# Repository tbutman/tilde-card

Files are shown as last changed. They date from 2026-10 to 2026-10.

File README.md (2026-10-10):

# Tilde card

A business card you print yourself, made to go with [Tilde](https://taptilde.com), the
Android app that turns your phone into an NFC business card. The front has a QR code that opens your
website. Add an NFC sticker, sealed inside during the print, and people can tap it with their phone
too.

**Free and open source.** The model is free to download, print and change: MIT for the source,
CC BY 4.0 on MakerWorld. No account, sign-up, subscription or payment, and no service in between:
the card links straight to your own website. It works without the app too: phones read it on their
own, and any NFC app can write the sticker. More about Tilde and the card:
[taptilde.com](https://taptilde.com).

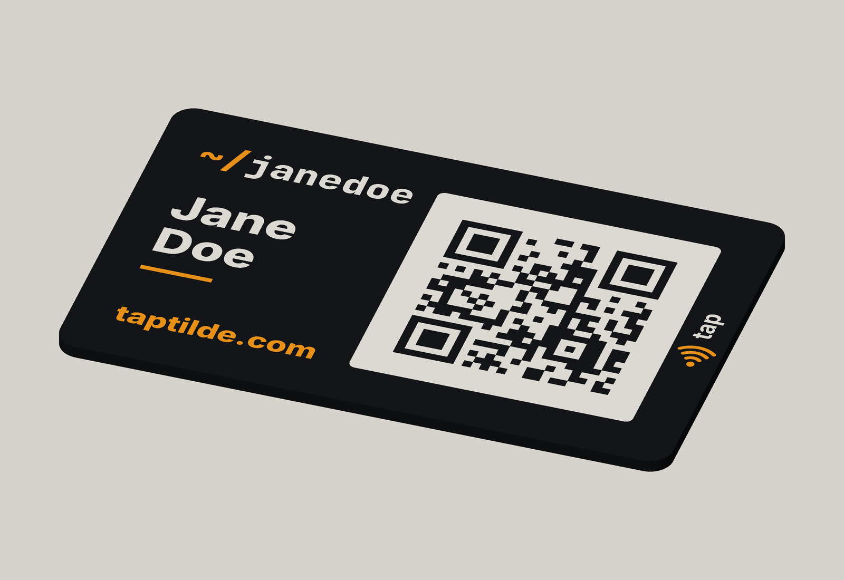
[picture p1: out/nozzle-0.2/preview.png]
The card


| Front | Back |
| --- | --- |
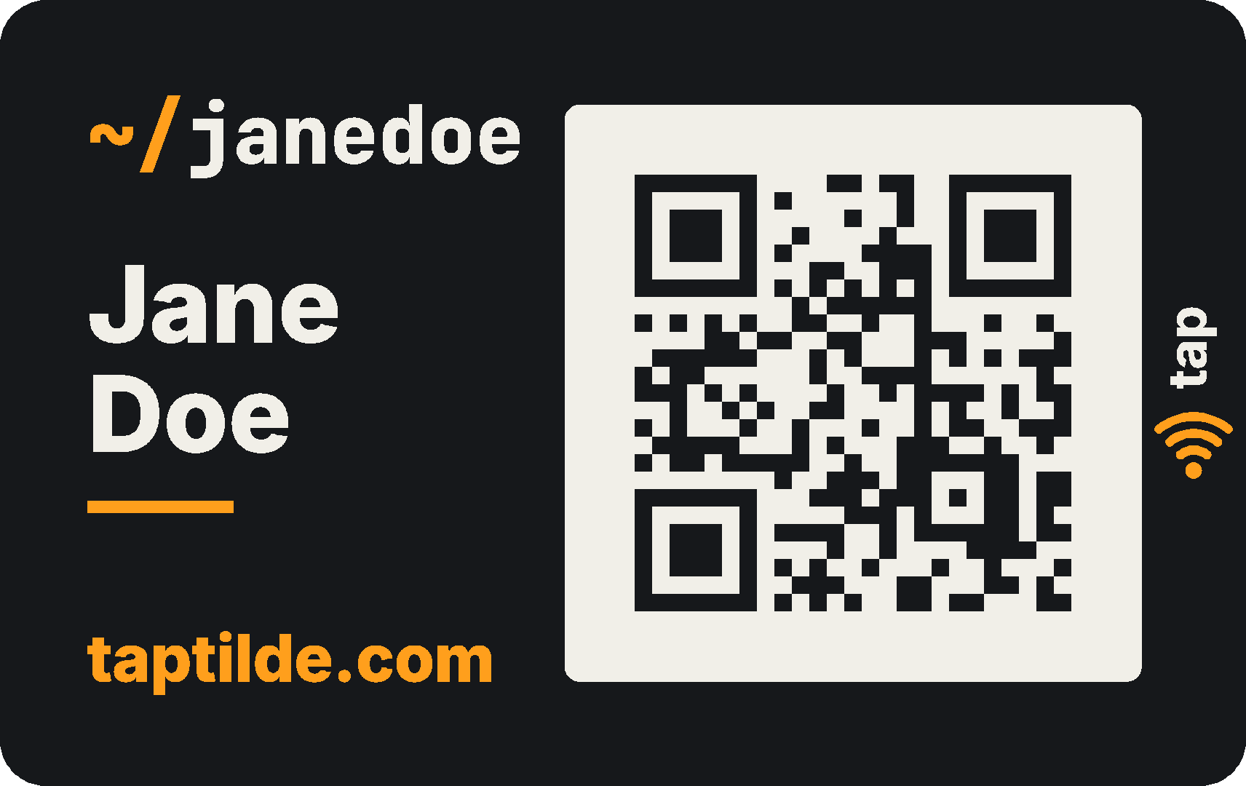
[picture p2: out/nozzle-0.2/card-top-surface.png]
Front
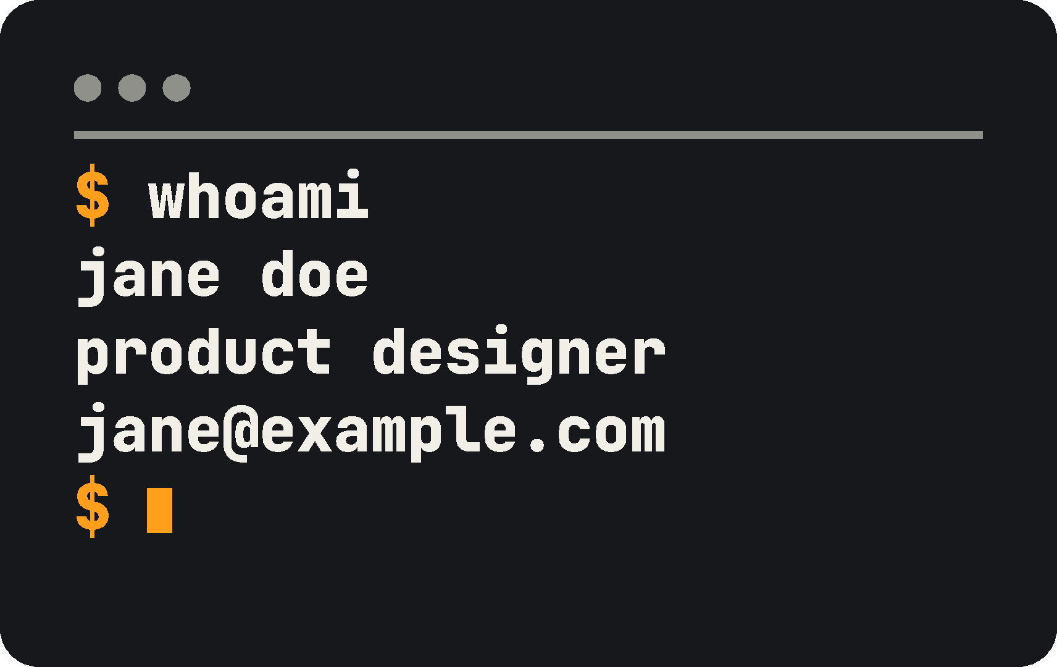
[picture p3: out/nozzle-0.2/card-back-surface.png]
Back
|  |  |

- **Credit-card size** (85.6 × 54 mm), 1.6 mm thick (1.8 mm with an NFC sticker, 2.0 mm with a thick one), so it fits
  a wallet.
- **A QR code that works with any phone camera.** It's the heart of the card.
- **NFC is optional.** If you add it, the printer pauses halfway, you drop in a sticker, and the
  rest of the card prints over it, sealing it inside; iPhones and Android phones with NFC then open
  your link when tapped against the marked spot. Without one, it's a QR card: no stickers and no
  pause.
- **Three backs to choose from:** a terminal window (`$ whoami`, as above), a plain one, or none,
  which prints fastest. Both designs print three lines you choose, such as your name, title and
  email.
- **Four colors of PLA**, printed all at once on a printer with an AMS (or another multi-color
  system). No painting or gluing.

The files in `out/` are a sample card for Jane Doe, an example person, linking to taptilde.com. To
make yours, type in your name, links and colors on MakerWorld (coming soon) or in OpenSCAD's
Customizer: see [Make it yours](PRINTING.md#make-it-yours). The Customizer starts on the 0.4 mm
nozzle, the faster print and the one most printers come with; see
[Choose a nozzle](PRINTING.md#choose-a-nozzle).

## Print one

[PRINTING.md](PRINTING.md) walks through it step by step: which nozzle to use, the slicer settings
and, if you add NFC, which stickers to buy, the pause for the sticker and how to put your link on
it.

## Tilde, the app it goes with

[Tilde](https://github.com/tbutman/tilde) is a free, open-source Android app (MIT, no account, no ads,
no internet permission) that does what the card does, from your phone: people tap your phone, or scan the code on its screen, to get your website,
contact card, WhatsApp or LinkedIn. It also writes your link onto the card's NFC sticker
(**Settings → Write a sticker**). Get it at [taptilde.com](https://taptilde.com).

## For developers

The model is written in [OpenSCAD](https://openscad.org): `card.scad` holds every size and every
line of text as a setting. [docs/DESIGN.md](docs/DESIGN.md) covers how it's built and checked,
the design decisions, and the print log.

## License

The model and scripts are [MIT](LICENSE) © Thomas Butman. The printable files on MakerWorld are
shared under [CC BY 4.0](https://creativecommons.org/licenses/by/4.0/): print, remix and sell
cards freely, with credit. The fonts in `fonts/` are Inter and JetBrains Mono, under the SIL Open
Font License (see the license files beside them).

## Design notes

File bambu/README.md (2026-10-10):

# Bambu Studio process presets

Two process presets for the **Bambu Lab A1 mini**, one per nozzle. They build on the A1 mini's
standard processes and change only what the card needs:

| Preset | Builds on | Changes |
| --- | --- | --- |
| `Tilde card 0.4 mm` | 0.20mm Standard @BBL A1M | Sparse infill 100% with the Rectilinear pattern (`zig-zag` in the file), Arachne walls, Monotonic line bottom surface, and paint penetration layers top 2 / bottom 2 |
| `Tilde card 0.2 mm` | 0.10mm Standard @BBL A1M 0.2 nozzle | The same, with paint penetration layers top 4 / bottom 4 |

The paint penetration layers matter for a 3MF from MakerWorld's Customize: its colors are painted
onto one shape, and Bambu Studio paints each face this many layers deep. These values keep the
back's colors to its 0.4 mm inlays, above the black lid over the sticker. Bambu also paints the
pocket's ceiling black upward as a bottom face, so the bottom value is 2 (4): more would fill the
letters over the pocket with black. The front's white is then 0.4 mm with black behind it, which
hides the sticker. With the defaults (top 5 on 0.4 mm, 7 on 0.2 mm) the back's letters go through
the lid and print onto the sticker. The STL parts in `out/` aren't painted, so they're not affected.

Both presets are tested on real prints of a sticker card from a Customize 3MF, paint penetration
layers included (October 8, 2026): the 0.4 mm one fully, the 0.2 mm one through to the last layer,
where the 0.2 mm nozzle clogged, so its back's white came out one layer short. A tap test and
photos of the 0.2 mm card are still to come. Before printing
a sticker card, check the lid in Preview (see [PRINTING.md](../PRINTING.md#set-up-the-print-in-bambu-studio), step 7).

**To use them:** in Bambu Studio, **File → Import → Import Configs**, choose
`tilde_card_bambu_printer_settings.zip` (or one of the `.json` files), then pick **Tilde card 0.4 mm** or
**Tilde card 0.2 mm** under **Process**, with the A1 mini and the matching nozzle selected. The
pause for an NFC sticker is still added by hand (see [PRINTING.md](../PRINTING.md#add-the-pause-for-the-nfc-sticker)).

**Updating from an earlier version?** Delete the old Tilde card preset first, or check that Top
paint penetration layers shows 2 (0.4 mm) or 4 (0.2 mm) after importing. Bambu Studio may keep an
existing preset with the same name, and an older export doesn't set the paint layers.

**After opening the 3MF, choose the process again** (Tilde card 0.4 mm or 0.2 mm, or your adjusted
standard process): the 3MF from Customize is a Bambu project file and brings Bambu's standard
process with it. If the name shows an asterisk, re-select it and discard the changes. Then check
Top paint penetration layers shows 2 (0.4 mm) or 4 (0.2 mm).

On another printer, start from its own standard process and make the four changes by hand
(see [PRINTING.md](../PRINTING.md#set-up-the-print-in-bambu-studio)).

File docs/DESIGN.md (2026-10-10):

# Design and build notes

The technical side of the card: how the model is built, checked and generated. To print one, see
[PRINTING.md](../PRINTING.md).

## Specifications

- **Size:** ID-1 (85.60 × 53.98 mm, 3.2 mm corners), 1.6 mm thick as a QR card; 1.8 mm with thin
  stickers, 2.0 mm with thick ones.
- **QR code:** generated in `card.scad` from `qr_code_link`: byte mode, version 1–3 with error
  correction M (or L when M can't hold the link), up to 53 characters. The modules scale to fill a
  fixed 39.6 mm white field that includes the full 4-module quiet zone: 1.37 mm (version 1),
  1.2 mm (version 2, as for `https://tbutman.com/hello`) or 1.07 mm (version 3). Black modules on
  white; the white is a 0.6 mm inlay, flush with the face.
- **NFC (optional):** `nfc_sticker = "none"` leaves out the pocket and the tap marker, for a QR
  card with no pause; the QR code keeps its place. Otherwise, an NTAG215 sticker (22–25 mm across, 25.5 mm at most) in a 25.8 mm pocket against the right edge, under the QR code,
  with 0.8 mm of plastic between it and the front face (the 0.6 mm inlay and 0.2 mm of black, so
  the tag can't show through the white field). The pocket is 0.2 mm deep for stickers 0.10–0.20 mm
  thick, or 0.4 mm deep with `nfc_sticker = "thick"`. Over the tag (the first layers after the
  pause) is a solid black lid of 0.4 mm (`nfc_lid_t`), then the back's inlays, which are 0.4 mm deep
  on a sticker card (0.6 mm on a QR card): the first print with a sticker had the back's letters
  printed straight onto the sticker, and they dragged into strings. So a sticker card is 1.8 mm
  thick, or 2.0 mm with thick stickers. A tap marker (NFC waves, not the EMVCo payment symbol, and
  `tap_label`, "tap" by default), turned to read upwards, sits in the strip right of the QR code,
  over the tag. The waves and the label each take one of the card's colors (`tap_waves_color`,
  `tap_label_color`: `accent`, `light` or `chrome`; by default the accent color for the waves and the light color for the label), on
  both sides; each goes into that color's inlay part, flush with the face. A longer label shrinks to fit the QR code's height, down to the
  nozzle's smallest text (about 14 characters on 0.4 mm, 17 on 0.2 mm); an empty one leaves just
  the waves. `back_tap_mark` (`waves` or `label`) repeats the marker on the back: the waves, plus
  `tap_label` for `label`, turned like the front's, in the same strip seen from behind, so it sits
  over the tag. With the mark on, the back's lines (and the terminal window) start 2.69 mm further
  right, a `text_gap` past the strip, on all three styles; with it off, nothing moves.
  The back's mark uses the same two colors. On a None back the mark brings back the back's inlay
  layers (about one more color change per layer: 6 layers on 0.2 mm, 3 on 0.4 mm), and with the
  window bar color the gray filament too; the window bar color on the front adds it to the front's
  layers the same way.
  `verify.py` lists the sample's reviewed spots at both positions.
- **Back:** `back_style` is `terminal`, `plain` or `none` (plain black). Both designs print the
  same three lines, `back_line_1` to `back_line_3`; an empty one is skipped. The terminal style is
  a window: a gray title bar (three dots and a rule), then a session (`$ ` and `terminal_command`,
  `whoami` by default, the three lines, a cursor) anchored under it, inlaid 0.6 mm (0.4 mm with a sticker). The plain style
  prints the lines in Inter, centered vertically: the first larger, the second in the accent color. Both shrink
  to fit like the front. The back reads correctly when the card is turned over sideways.
- **Print orientation:** the front prints face-down (`face_down = "front"`), because the plate
  side came out flat and matte on the first sample and the top side came out ridged. The STLs
  are exported already lying that way: the model turned over about its long axis, a rotation
  rather than a mirror. `verify.py` turns each face back the right way round before checking it.
- **Type:** Inter (ExtraBold; Bold for "tap" on the 0.2 mm version) and JetBrains Mono ExtraBold, the site's
  own typefaces, unaltered. Tuned for a 0.2 mm nozzle on 0.1 mm layers: cap heights of 2.6 mm or
  more, every stroke at least 0.3 mm and every gap at least 0.22 mm, on both faces.

Two versions are built from the same model, `out/nozzle-0.2/` and `out/nozzle-0.4/`; see
[Choose a nozzle](../PRINTING.md#choose-a-nozzle).

## Files

| Path | What |
| --- | --- |
| `card.scad` | The parametric model, one self-contained file. The Customizer sections at the top are the settings people change, one help line each (MakerWorld shows only one); `[Hidden]` holds the layout. The defaults are the sample card, Jane Doe. |
| `card.local.example.scad` | A template for `card.local.scad` (git-ignored): your own settings, one `setting = value;` per line, which `build.sh` passes to OpenSCAD as `-D` flags. |
| `makerworld/tilde-card.scad` | The copy uploaded to MakerWorld's customizer, written by `scripts/make_makerworld.py`: no font file lines, and the example person Jane Doe as the defaults. Never edited by hand. |
| `out/makerworld-sample/`, `out/makerworld-sample-qr-only-plain/` | Cards built from the MakerWorld copy, to check it renders and passes the checks: the default (on its default 0.4 mm nozzle, checked against that nozzle's limits), and one with no NFC sticker and the plain back (its first line typed as "Jane Doe"). |
| `out/nozzle-{0.2,0.4}/card-{body,light,accent,chrome}.stl` | The sample card (Jane Doe): one STL per color (black, white, orange, gray), per nozzle, for stickers up to 0.2 mm. |
| `out/nozzle-{0.2,0.4}-thick-sticker/` | The same for stickers up to 0.4 mm: a 2.0 mm card with a deeper pocket. |
| `out/nozzle-*/card-{top,back}-surface.png` | Each face as printed, rasterized from the STLs (the back as seen from behind); the QR check decodes the front. |
| `out/nozzle-*/preview.png` | A 3/4 render of the front, from the color STLs. |
| `out/local/` | Your own card, built from `card.local.scad` when it exists, in the same layout as `out/`. Git-ignored. |
| `bambu/` | Bambu Studio process presets for the A1 mini, one per nozzle (`Tilde card 0.4 mm`, `Tilde card 0.2 mm`), with the card's settings and paint penetration layers, and the same two in a zip to import; see `bambu/README.md`. |
| `test/` | `sticker-test.scad`, the card-sized tile that chose the solid lid (see [Solid lid](#solid-lid-8-october-2026)); `test/build-sticker-test.sh` exports its STLs and a 3MF into `test/out/`, and `test/README.md` gives its pause layers. |
| `fonts/` | Static instances of the site's variable fonts (SIL Open Font License; see the license files). |
| `scripts/` | Checks (`verify.py`, `test_qr.py`), the preview render, the MakerWorld copy and the MakerWorld cover options (`make_covers.py`, into `makerworld/images/covers/`, and the chosen one to `makerworld/images/01-cover.png`) and the MakerWorld model pictures (`make_listing_images.py`, `makerworld/images/02`–`07`). |

## Build

Needs Docker (OpenSCAD runs in the official `openscad/openscad:dev` image, so nothing needs
installing) and Python 3.10 or newer (Homebrew's `python3.13` here):

```bash
python3.13 -m venv .venv && .venv/bin/pip install -r requirements.txt
./build.sh
.venv/bin/python scripts/test_qr.py
```

For each nozzle (`./build.sh 0.2` builds just one) and sticker thickness, `build.sh` exports the
four STLs, runs the checks below and re-renders the preview: the sample card into `out/`, and, if
`card.local.scad` exists, your own card into `out/local/` (copy `card.local.example.scad` to start). Then it writes the MakerWorld copy
and builds and checks a sample card from it, with the fonts found by name as MakerWorld finds
them. To try settings interactively, open `card.scad` in any recent OpenSCAD and use the
Customizer.

`card.scad` refuses to render, with a message saying what to change, if the link is over 53
characters, if a name, handle, website or line on the back won't fit at the nozzle's smallest
printable size (`min_cap`), if a module is under 1 mm, if the inlay is under 0.4 mm, if text is under `min_cap`, if a thickness is not a whole
number of layers, or if the NFC pocket has fewer than two layers over it, less than a 0.4 mm solid
lid between it and the back's inlays, or less than 2 mm of wall to any edge. The `nozzle` parameter (0.2 or 0.4) sets those limits (`layer_h`,
`min_stroke`, `min_gap`, `min_cap`) and the few design differences; `build.sh` passes the same
limits to `verify.py`.

## Checks

`build.sh` also runs `scripts/check_pause_docs.py`: the pause layers in the `nfc_sticker` help
line (which MakerWorld's Customizer shows), the listing's table and plain lines, and PRINTING.md's
table must match the model's computed `pause_layer` for every nozzle and sticker built.

`scripts/verify.py` checks the exported STLs, not the source:

- every color body is manifold (each edge shared by exactly two triangles);
- with a sticker, nothing but black sits over the pocket for 0.4 mm: every inlay that reaches above
  the pocket's ceiling starts at least 0.4 mm higher (`build.sh` passes the ceiling's height from
  the model);
- the front, rasterized from the STLs in print colors, decodes with ZXing to exactly the link:
  at 20 px/mm, at 4 px/mm, and with a heavy blur. OpenCV's decoder runs too, as a warning only:
  it misses some valid symbols (for `https://tbutman.com/hello`, masks 5 and 6 at full
  resolution, including segno's own), which ZXing reads;
- on both faces, opening each text mask with a `min_stroke` disk (0.3 mm / 0.5 mm) loses nothing
  larger than a glyph-corner sliver (0.06 mm²): no stroke is thinner than that. Pointed stroke
  ends can lose a little more though the stroke is wide enough, so each reviewed one is listed in
  `KNOWN_THIN_TIPS`, matched by position so a change to the text brings the check back (currently
  the four arm tips of the `x` in the sample's `jane@example.com` on the 0.4 mm back, 0.072 mm²
  each: they print slightly blunt);
- closing it with a `min_gap` disk (0.22 mm, one 0.2 mm line / 0.34 mm, the slicer's narrowest
  wall for a 0.4 mm nozzle) fills nothing: no gap inside or between letters is narrower. Acute
  inner corners always fill a little, so each reviewed one is listed in `KNOWN_ACUTE_CORNERS`
  (currently the middle of the back's `w`).

Result on the current files: the 0.2 mm version passes everything. The 0.4 mm version passes
everything except the gap check, which it reports as warnings rather than failures: about 6 spots
on the front and 40 on the back, mostly inside the back's monospace letters. That is the 0.4 mm
nozzle's limit, and the reason for the 0.2 mm version. These checks are on the digital model;
see the print log for real prints.

## What happens at each layer

With thin stickers the card is 1.8 mm thick. With the 0.2 mm nozzle that is 18 layers of 0.1 mm:

| Layer | Height (top of layer) | Contents |
| --- | --- | --- |
| 1–6 | 0.10–0.60 mm | The front, face-down: black, white and orange inlays; the AMS swaps colors on each layer |
| 7–8 | 0.70–0.80 mm | Black |
| 9–10 | 0.90–1.00 mm | Black, with the open NFC pocket (25.8 mm round, under the QR code, against the card's right edge as seen from the front) |
| — | — | **Pause: drop in the NFC tag** |
| 11–14 | 1.10–1.40 mm | The lid: solid black over the tag |
| 15–18 | 1.50–1.80 mm | The back: black, white, orange and gray inlays |

With the 0.4 mm nozzle it is 9 layers of 0.2 mm:

| Layer | Height (top of layer) | Contents |
| --- | --- | --- |
| 1–3 | 0.20–0.60 mm | The front, face-down: black, white and orange inlays |
| 4 | 0.80 mm | Black |
| 5 | 1.00 mm | Black, with the open NFC pocket |
| — | — | **Pause: drop in the NFC tag** |
| 6–7 | 1.20–1.40 mm | The lid: solid black over the tag |
| 8–9 | 1.60–1.80 mm | The back: black, white, orange and gray inlays |

A QR card (no sticker) is 1.6 mm: 16 layers of 0.1 mm or 8 of 0.2 mm, with no pocket, no pause and
0.6 mm back inlays (layers 11–16, or 6–8).

### Thick stickers

These tables are for thin stickers. With `nfc_sticker = "thick"`, the card gains 0.2 mm of black
in the middle (2.0 mm in all): the pocket is 0.4 mm deep (0.8–1.2 mm above the plate), and the
pause moves to layer 13 (0.2 mm nozzle) or layer 7 (0.4 mm nozzle), with the same lid and back
after it. `build.sh` prints the pocket and pause for
every version. The model refuses to build if the tag would have fewer than two layers over it, or
less than 0.2 mm of black between it and the front inlays.

## Solid lid (8 October 2026)

**What failed.** The first card printed with a sticker (7 October 2026) had the back's inlays
straight over the pocket: the pocket's ceiling and the bottom of the 0.6 mm back inlays were the
same height. So the first layers after the pause were the back's letters (`whoami`, the `$`, the
name line), printed as small islands onto the sticker's smooth face, and they dragged into
strings. That print also showed the sticker through the front's white QR field as a pale disc.
`verify.py` only looked at finished surfaces, so it couldn't see either.

**The test.** `test/sticker-test.scad`: a card-sized tile, 1.8 mm thick, printed front down on the
0.4 mm nozzle, with two thin-sticker pockets:

- **B:** 0.2 mm of black between the front's 0.6 mm white and the sticker, a 0.4 mm lid (two
  layers) over it, then 0.4 mm back inlays.
- **2:** 0.4 mm of black in front, a 0.2 mm lid (one layer), then 0.4 mm back inlays.

Each had a white QR-like patch on the front and terminal-style letters right over it on the back,
plus a strip of white squares 0.2, 0.4 and 0.6 mm deep.

**Results** (Thomas, 8 October 2026, 0.4 mm nozzle):

- No sticker showed through the front's white over either pocket, even in bright light.
- The back's letters printed cleanly over both pockets.
- The two-layer lid came out flat; the single-layer lid was rippled.
- The 0.4 and 0.6 mm white squares looked the same; 0.2 mm was gray.

**Why option B.** Two layers of lid print flat where one ripples. 0.2 mm of black in front of the
sticker hid it on the tile, so the front stays as it was. And 0.4 mm of white is as opaque as 0.6.
So a sticker card has 0.4 mm back inlays and a 0.4 mm lid, and is 0.2 mm thicker: 1.8 mm with thin
stickers, 2.0 mm with thick. A QR card has no pocket and stays 1.6 mm with 0.6 mm back inlays.
`card.scad` asserts the lid, and `verify.py` checks it in the STLs. Not yet tested: the 0.2 mm
nozzle, and a full card with option B.

## Painted colors from Customize (8 October 2026)

**What happened.** The next card with a sticker, printed on the 0.4 mm nozzle from a 3MF made by
MakerWorld's Parametric Model Maker, had the 0.4 mm lid, but the back's letters still printed
onto the sticker. The Model Maker doesn't export the four color parts: it exports one shape with
the colors painted onto about 36,000 of its triangles (`paint_color` in the 3MF). Bambu Studio
decides how deep painted colors go with **Top paint penetration layers**
(`top_color_penetration_layers`) and **Bottom paint penetration layers**
(`bottom_color_penetration_layers`). On 0.20mm Standard @BBL A1M they're 5 and 3, so the back's
colors went 5 × 0.2 = 1.0 mm deep, through the lid and onto the sticker. On 0.10mm Standard
@BBL A1M 0.2 nozzle they're 7 and 5 (0.7 and 0.5 mm).

**How we found it.** The test tile and `verify.py` both use the STL parts, which aren't painted, so
the lid held there. The 3MF's `Metadata/project_settings.config` showed the two settings at their
defaults.

**The fix** is in the slicer settings, not the model:

- The `bambu/` presets set top / bottom paint penetration layers to 2 / 2 on the 0.4 mm nozzle and
  4 / 4 on 0.2 mm: 0.4 mm on each face. (At first the bottom was 3 / 6, for a 0.6 mm front; see
  below.)
- PRINTING.md and the listing list them as a fourth setting to change, with the reason, and add a
  check before printing: in Preview (color scheme Filament), the lid layers right after the pause
  must be all black over the pocket.
- QR cards are fine with the same values: 0.4 mm of white looked as white as 0.6 on the tile.

**What the model can't do.** Paint depth is a slicer setting, and the 3MF from Customize carries
the process the person picks, not ours. For the model alone to prevent it, the lid would have to
be thicker than Bambu's default paint depth: 1.0 mm on the 0.4 mm nozzle, which would make a
thin-sticker card 2.4 mm. Raised letters wouldn't help either, because paint penetrates down from
any top face. The `nfc_sticker` help line has no room left. So the safeguards are the presets,
MakerWorld print profiles uploaded with the model (they carry these settings to anyone who opens
the 3MF in Bambu Studio), and the listing's settings and Preview check.

**Print time.** With paint penetration 2 / 2 (4 / 4 on the 0.2 mm nozzle), fewer layers have
colors in them: 8 instead of 12 on the 0.2 mm nozzle, 4 instead of 6 on 0.4 mm. Color changes
happen once per color layer for the whole plate and dominate the time, so a card got quicker:
Bambu Studio estimates about 4 hours (3h55m, 21 color changes) for a thin-sticker card with the
terminal back on the 0.2 mm nozzle, from a Customize 3MF with the Tilde card 0.2 mm preset (it
was about 4½ hours). The 0.4 mm time is not yet measured with these settings (it was 75 minutes).
The front and the back each have half the color layers, so a card with no back has roughly half
the color changes.

**The pocket's ceiling (8 October 2026, later).** With the bottom value at 3, Thomas's next print
had the lid, but the back's letters over the pocket had no wells: they printed flat, as if filled
in. In painted mode Bambu also counts the pocket's ceiling (the underside of the lid) as a bottom
face, and painted its black 3 layers upward, through the 2-layer lid and into layer 8, where the
letters start. With the bottom at 2 (4 on the 0.2 mm nozzle), that black stops at the lid's top.
On a Customize print this also makes the front's white 0.4 mm instead of 0.6, with 0.4 mm of black
behind it: like the tile's pocket 2, which hid the sticker. Thomas checked 2 / 2 in Preview. The
Preview check now also looks at the first letter layer over the pocket and at layer 3 (black
under the front's white).

## Defaults (October 10, 2026)

The sample card is Jane Doe, an example person, linking to `https://taptilde.com` with
`taptilde.com` printed under the name; her email on the back stays `jane@example.com`, since
example.com is reserved and gets no mail. The Customizer starts on the 0.4 mm nozzle: it's the
faster print, the nozzle most printers come with, and the fully tested preset. A 0.2 mm design
printed on a 0.4 mm nozzle can lose its thin strokes, while a 0.4 mm design on a 0.2 mm nozzle just
comes out a little less sharp, so the safer default is 0.4. `build.sh` checks the MakerWorld sample
against the limits of whichever nozzle the file defaults to.

## Design notes

- The QR encoder is OpenSCAD functions in `card.scad`, so MakerWorld's customizer (one file, no
  local includes) can make a code for each person's link. It covers only what fits the card:
  byte mode, versions 1–3, levels M and L, single blocks. `scripts/test_qr.py` checks every
  version and mask: ZXing must decode each symbol, and symbols whose text fills them exactly must
  match segno module for module. (With shorter text, segno adds a `0x00` byte after the
  terminator that ISO/IEC 18004 7.4.10 doesn't call for, so those differ while both decode.) The
  mask is the one with the lowest penalty score; the scores match segno's scorer.
- Long text shrinks to fit rather than running into the QR code: the model sums each string's
  advance widths (a table read from Inter ExtraBold; JetBrains Mono is 0.822 per mm of size) and
  scales the size down to the column, never below the nozzle's `min_cap`. Measured against
  OpenSCAD's rendered ink, the estimate is within 2%, and the 1.5 mm gap before the QR field
  covers the difference. Two names shrink together, as do all the back's lines.

- The QR modules are the black body showing through the white field, so the code has no
  separate dark part. Dark modules are grown by 0.02 mm (`qr_overlap`), so diagonal neighbors
  overlap instead of meeting at a zero-width edge. That edge would make both STLs non-manifold.
- `JetBrains Mono` set the domain at first, but its narrow `m` has stems under 0.5 mm at this
  size. Inter's `m` is wider. The mono face stays for the `~/tbutman` mark, which matches the
  site header: amber `~/`, light `tbutman`. It is set as one string and split by color, so the
  spacing is the font's own.
- With a 0.4 mm nozzle, several glyphs need thickening to reach 0.5 mm strokes (the mono `a`
  joint, the `$` bar). The `*_bolden` parameters do that for the 0.4 version; for the 0.2 version
  they are all 0, so the letters print exactly as drawn.
- The tap label was "tap to connect" in white. It printed cleanly on the 0.2 mm sample, but the
  short "tap" reads better at a glance. It was amber for a while, matching the waves; it's now its
  own setting (`tap_label_color`), light by default, which stands out more against the accent
  waves. The 0.2 mm version keeps that
  sample's lighter Inter Bold at 2.6 mm (Thomas preferred it); the 0.4 mm version uses ExtraBold at
  3 mm, since Bold's strokes are too fine for that nozzle. (Earlier note: at 2.6 mm, ExtraBold's
  `c` and `e` openings were about 0.15 mm and would have printed closed.)
- The tap marker sits right of the QR code, where the NFC tag now is. The tag first sat behind
  the name, under a non-QR area as the original brief asked; it moved so the marker could go
  in that strip and still point at the tag. Phones read NFC from only 1–3 cm away, so a marker
  away from the tag would send people to a dead spot. The trade-off: the tag is under the QR
  code, so check on the first print that the QR face stays flat over it.
- In OpenSCAD 2026.09, `text(size = s)` gives a cap height of about `s` mm for both fonts
  (measured: an `H` at size 10 is 10.1 mm), so the sizes above are cap heights.

## Counting scans

The site promises 0 cookies and 0 trackers, so there are no analytics scripts. Visits are counted
from nginx's own access log instead: since 5 October 2026 the site's server keeps that log (four
weeks) and builds a private GoAccess report from it every 15 minutes, with `/hello` among the
pages and referring sites (see the site repository's `deploy/README.md`). For a quick count on the
server, in the site's Docker Compose directory:

```bash
sudo docker compose logs --no-log-prefix website | grep -c '"GET /hello'
```

This counts requests, not people. The QR code, the NFC tag and Tilde on Thomas's phone all open
the same URL, so they can't be told apart. Link-preview bots and reloads count too. The Docker
log only goes back to when the container was last recreated; the report keeps longer history.

## Print log

| Date | Cards | Result |
| --- | --- | --- |
| 2026-10-05 | 1, 0.4 mm nozzle, no tag, front face-down (design as of a1a15f1) | 75 minutes. Front: smooth and matte, crisp QR code, name and domain; the "tap" label and waves too small to read, and concentric first-layer rings in the black (fix: bottom surface pattern). Back, printed on top: legible but ridged and a little soft; `@`, `m` and `$` slightly blobby, as the 0.4 mm gap check predicted. Led to making front-down the default orientation and to the 0.2 mm version. QR and tap not yet tested on phones. |
| 2026-10-05 | 1, 0.2 mm nozzle, front face-down, white "tap to connect" label | Significantly better than the 0.4 mm sample (Thomas, comparing photos): the back's small mono text is crisp, where the 0.4 mm sample's `@`, `m` and `$` were soft. He preferred this version's lighter label weight and asked for a shorter "tap" label in amber (later changed to a light label by default; see Design notes). Tag and phone tests still to come. |
| 2026-10-07 | 1, Thomas's card with an NFC sticker | The back's letters over the pocket printed straight onto the sticker and dragged into strings, and the sticker showed through the front's white QR field as a pale disc. Led to the solid lid. |
| 2026-10-08 | The sticker test tile, 0.4 mm nozzle, two pockets (B and 2) | No show-through over either pocket; clean letters over both; the two-layer lid flat, the one-layer lid rippled; 0.4 and 0.6 mm white the same, 0.2 mm gray. Option B chosen. See [Solid lid](#solid-lid-8-october-2026). |
| 2026-10-08 (03:07) | 1, 0.4 mm nozzle, from a Parametric Model Maker 3MF with a sticker, Bambu's 0.20mm Standard process | The 0.4 mm lid printed, but the back's painted colors went 5 layers (1.0 mm) deep, through it and onto the sticker, and dragged into strings again. Led to the paint penetration settings. See [Painted colors from Customize](#painted-colors-from-customize-8-october-2026). |
| 2026-10-08 (04:18) | 1, 0.4 mm nozzle, from a Customize 3MF, paint penetration 2 / 3 | The lid held, but Bambu painted the pocket's ceiling black 3 layers up, so the back's letters over the pocket printed without their wells. Led to 2 / 2 (4 / 4 on 0.2 mm). |
| 2026-10-08 | 1, 0.4 mm nozzle, from a Customize 3MF with a thin sticker, the Tilde card 0.4 mm preset (paint penetration 2 / 2), pause at layer 6 | Right. The front's white is even, with no sticker showing through, and every letter on the back is clean, including over the pocket. The first card with a sticker that came out as designed; the 0.4 mm preset is now print-tested, paint layers included. |
| 2026-10-08 | 1, 0.2 mm nozzle, from a Customize 3MF with a thin sticker, the Tilde card 0.2 mm preset (paint penetration 4 / 4; Bambu Studio's estimate 3h55m, 21 color changes), pause at layer 11 | The lid and the letters over the pocket printed correctly. The 0.2 mm nozzle clogged on the very last layer, so the back's white is one layer short and slightly translucent. Thomas counts the settings as tested; a tap test and photos are still to come. |

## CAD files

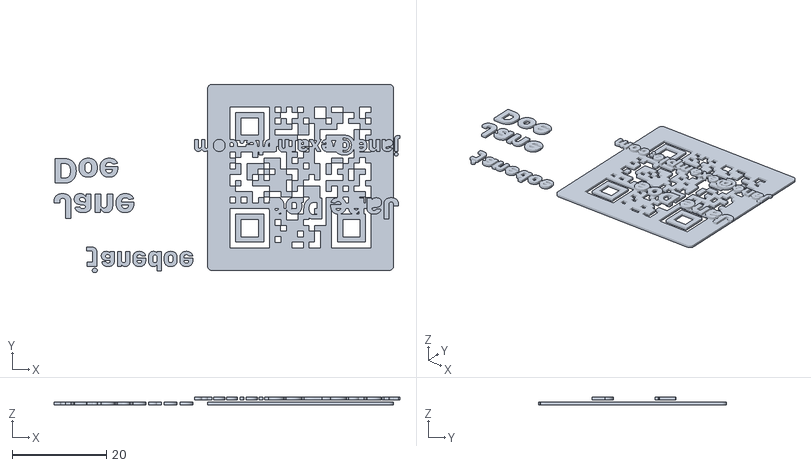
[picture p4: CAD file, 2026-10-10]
out/makerworld-sample-qr-only-plain/card-light.stl
73.6 x 40.1 x 1.60

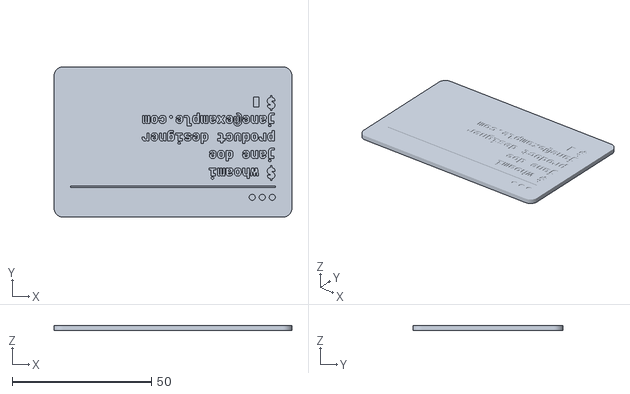
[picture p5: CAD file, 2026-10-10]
out/makerworld-sample/card-body.stl
85.6 x 54.0 x 1.80

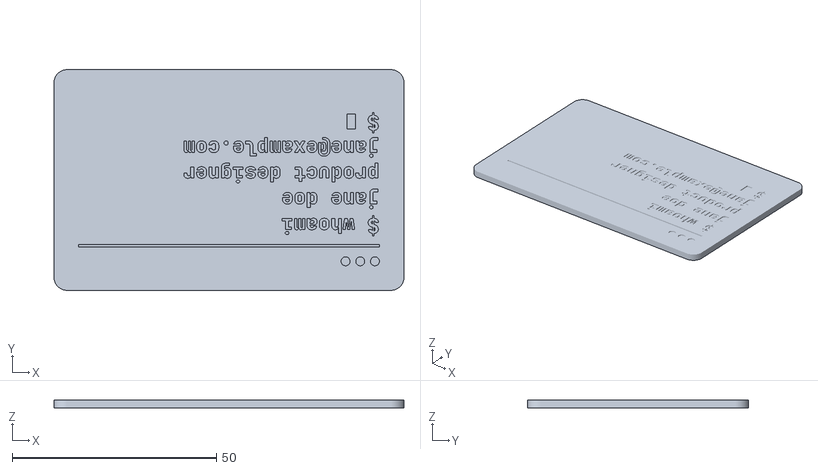
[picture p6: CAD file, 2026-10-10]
out/nozzle-0.2-thick-sticker/card-body.stl
85.6 x 54.0 x 2.00

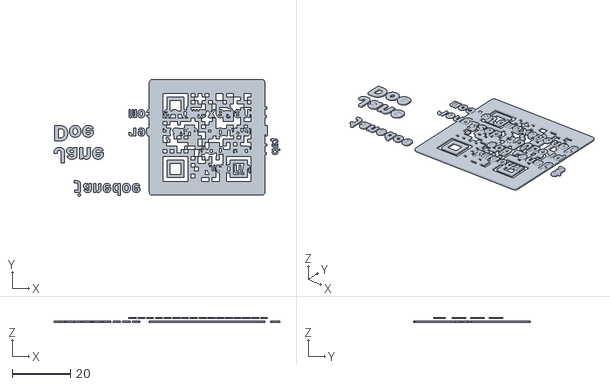
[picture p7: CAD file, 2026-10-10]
out/nozzle-0.2/card-light.stl
77.4 x 40.0 x 1.80

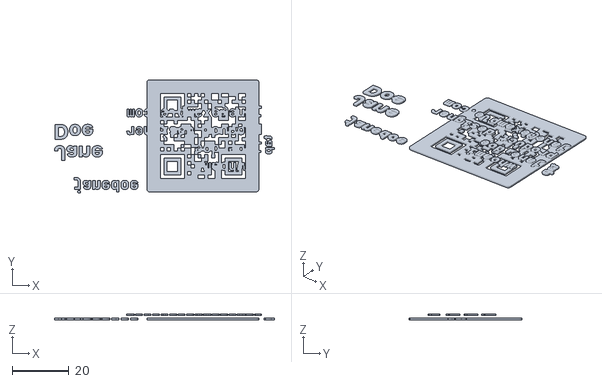
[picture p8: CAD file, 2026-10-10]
out/nozzle-0.4-thick-sticker/card-light.stl
77.7 x 40.1 x 2.00

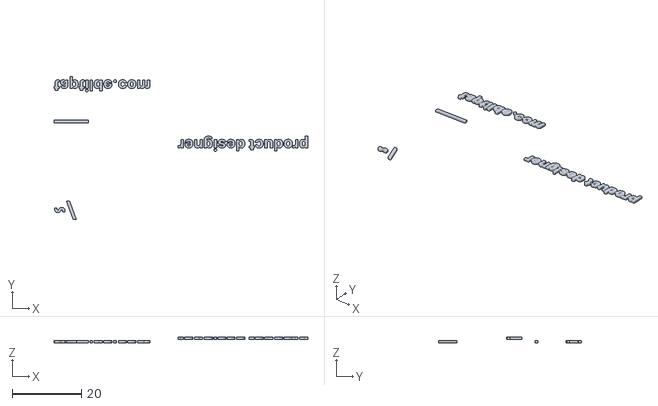
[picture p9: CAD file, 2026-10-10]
out/makerworld-sample-qr-only-plain/card-accent.stl
73.4 x 41.2 x 1.60

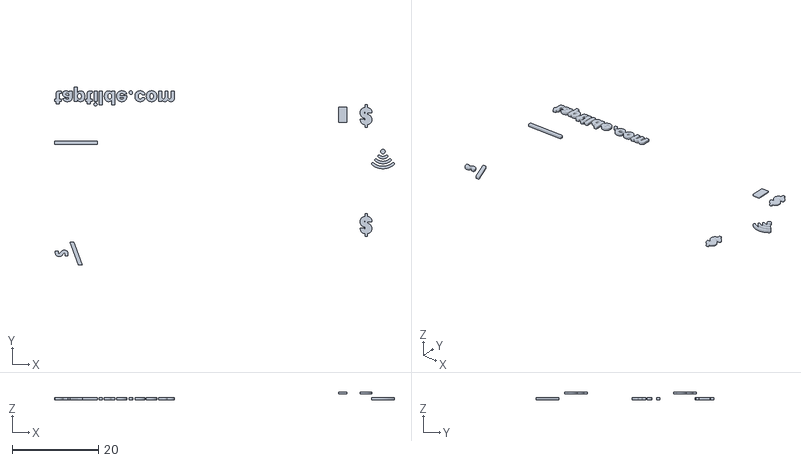
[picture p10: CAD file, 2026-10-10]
out/makerworld-sample/card-accent.stl
78.7 x 41.2 x 1.80

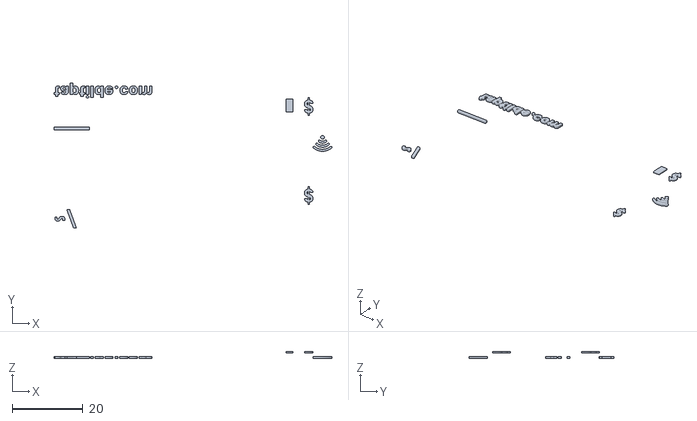
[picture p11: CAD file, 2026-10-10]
out/nozzle-0.2-thick-sticker/card-accent.stl
78.7 x 41.1 x 2.00

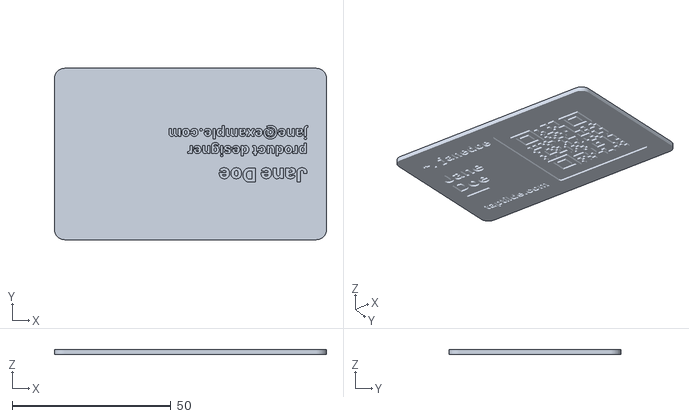
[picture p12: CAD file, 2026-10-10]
out/makerworld-sample-qr-only-plain/card-body.stl
85.6 x 54.0 x 1.60

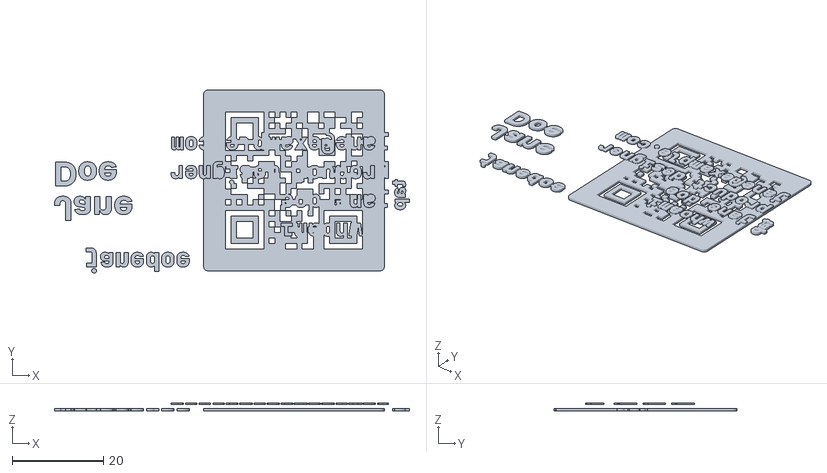
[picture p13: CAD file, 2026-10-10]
out/makerworld-sample/card-light.stl
77.7 x 40.1 x 1.80

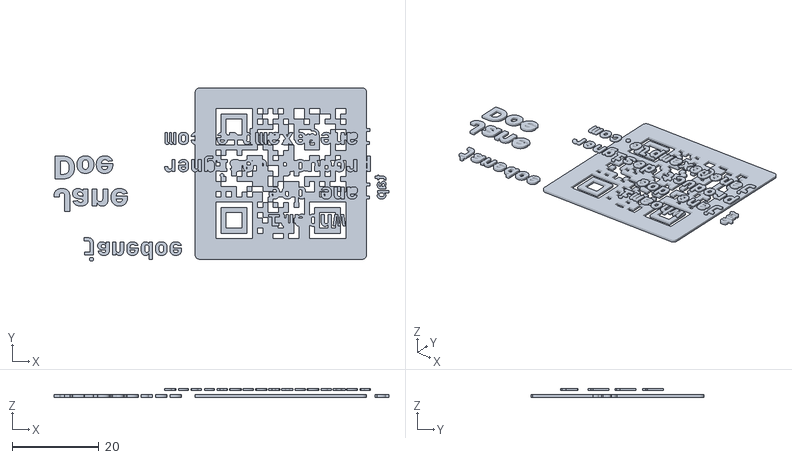
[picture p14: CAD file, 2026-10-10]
out/nozzle-0.2-thick-sticker/card-light.stl
77.4 x 40.0 x 2.00

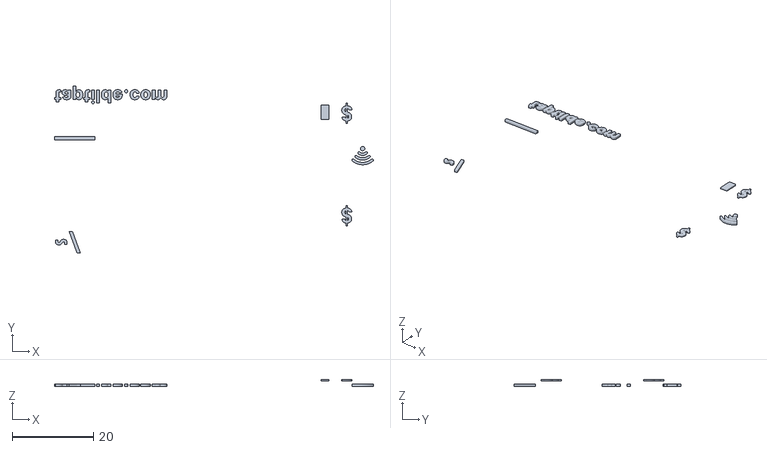
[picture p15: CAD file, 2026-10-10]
out/nozzle-0.2/card-accent.stl
78.7 x 41.1 x 1.80

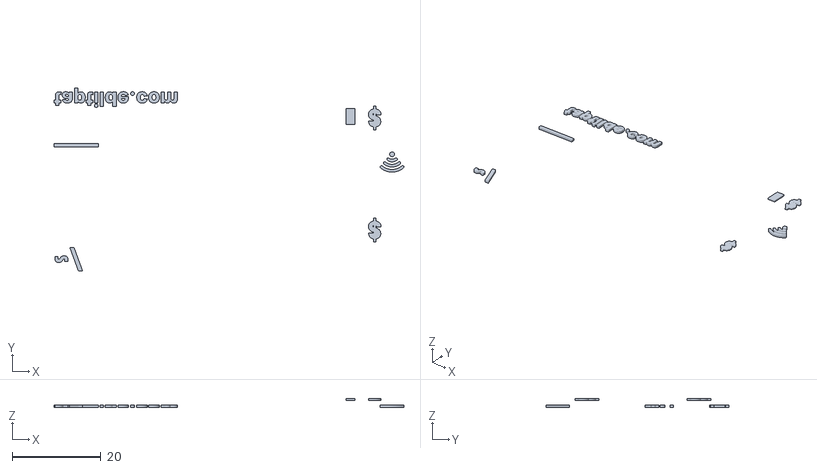
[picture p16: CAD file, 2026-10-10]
out/nozzle-0.4-thick-sticker/card-accent.stl
78.7 x 41.2 x 2.00

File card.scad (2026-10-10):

// Tilde card: a printable business card with your name and website on the front, a QR code that
// opens your link, an optional NFC sticker that does the same, and a choice of back.
//
// Open it in OpenSCAD's Customizer (or MakerWorld's) and fill in the first sections; everything
// under [Hidden] is the layout. One color body per part: body (black), light (white), accent
// (orange) and chrome (gray, the back's window bar). The light and accent parts are flush inlays in
// both faces; the dark QR modules are the black body showing through the white field. The QR code
// is generated here, so the model is a single file.
//
// The settings, one help line each (MakerWorld shows only one):
// - Front: your name over one or two lines, the ~/ handle, the QR code's link and your website.
//   Long text shrinks to fit; if it still won't, the preview stops with a message saying what to
//   change.
// - Back: three lines that both styles share. The terminal window prints "$ " and the command,
//   then the lines, then a cursor, in JetBrains Mono; the plain back prints the lines in Inter, the
//   first larger and the second in the accent color; none is plain black. Empty lines are
//   skipped, and long lines shrink to fit.
// - Tap mark (only with an NFC sticker): tap_label is the word by the tap waves; it shrinks to fit
//   the QR code's height. The waves and the label each take one of the card's colors, on both
//   sides. With back_tap_mark, they are repeated on the back, in the strip over the sticker (the
//   front's tap strip seen from behind), and the back's lines move right.
// - Printing: the nozzle and NFC sticker change the layers, the pocket and the pause; PRINTING.md
//   explains them. Up to 0.20 mm stickers are thin (a 1.8 mm card), up to 0.40 mm thick (2.0 mm); a
//   QR-only card is 1.6 mm.
//
// The defaults are the sample card, Jane Doe. build.sh builds your own card from card.local.scad
// when it exists (see card.local.example.scad).
//
// part = "preview" gives all four in color; build.sh exports one STL per part with -D part=...

// Local copies of the fonts. The MakerWorld copy (scripts/make_makerworld.py) leaves these lines
// out: MakerWorld has the same Google Fonts installed under these names.
use <fonts/Inter-ExtraBold.ttf>
use <fonts/Inter-Bold.ttf>
use <fonts/JetBrainsMono-ExtraBold.ttf>

/* [Front of the card] */
// Your first name, on the first line. Example: Jane
first_name = "Jane";
// Your last name, on the second line. Leave it empty to fit your whole name on one line. Example: Doe
last_name = "Doe";
// Shown after ~/ at the top, like a folder in a terminal. Leave it empty to leave it out. Example: janedoe
handle = "janedoe";
// The link the QR code opens: up to 53 characters. Write the same one to your NFC sticker. Example: https://example.com
qr_code_link = "https://taptilde.com";
// Your website, printed under your name. Leave it empty to leave it out. Example: example.com
website_on_card = "taptilde.com";

/* [Back of the card] */
// What the back shows. None is plain black and prints fastest, with about half the color changes.
back_style = "terminal"; // [terminal:Terminal window (a command and your lines), plain:Plain (your lines), none:None (plain black)]
// The command shown after $ on the Terminal window back. Example: whoami
terminal_command = "whoami";
// Printed on the back, in either style. Leave a line empty to skip it. Example: jane doe
back_line_1 = "jane doe";
// Printed on the back, in either style. Leave a line empty to skip it. Example: product designer
back_line_2 = "product designer";
// Printed on the back, in either style. Leave a line empty to skip it. Example: jane@example.com
back_line_3 = "jane@example.com";

/* [Tap mark] */
// The word next to the tap waves, up to about 14 characters (17 on the 0.2 mm nozzle). Leave it empty for just the waves. Example: tap to connect
tap_label = "tap";
// Which of your colors the tap waves use, on the front and the back.
tap_waves_color = "accent"; // [accent:Accent color, light:Light color, chrome:Window bar color]
// Which of your colors the tap label uses, on the front and the back.
tap_label_color = "light"; // [light:Light color, accent:Accent color, chrome:Window bar color]
// Show the tap waves on the back too (only with an NFC sticker). "Waves and label" uses your tap label.
back_tap_mark = "no"; // [no:No, waves:Waves only, label:Waves and label]

/* [Colors] */
// The card, and the QR code's dark squares. Keep it dark so the code scans.
card_color = "#16181b"; // color
// The QR code's background, your name, the back's text and the tap label. Keep it light so the code scans.
light_color = "#f1efe8"; // color
// The ~/, the line under your name, your website and the tap waves.
accent_color = "#ff9f1c"; // color
// The window bar on the terminal back.
window_bar_color = "#8e9089"; // color

/* [Printing] */
// Your printer's nozzle. 0.2 mm prints the sharpest text; 0.4 mm is over three times faster.
nozzle = 0.4; // [0.2:0.2 mm nozzle (sharpest), 0.4:0.4 mm nozzle (fastest)]
// An NFC sticker sealed inside lets phones tap the card: round, 22-25 mm (25.5 at most). Thin up to 0.20 mm, thick up to 0.40. Pause at layer 6 (thin) or 7 (thick) on a 0.4 mm nozzle, 11 or 13 on 0.2 mm.
nfc_sticker = "thin"; // [none:No NFC sticker (QR code only), thin:Thin NFC stickers 0.10-0.20 mm (1.8 mm card), thick:Thick NFC stickers 0.20-0.40 mm (2.0 mm card)]

/* [Hidden] */
part = "preview"; // preview, body, light, accent or chrome
// Which face prints against the plate. The plate side comes out flatter and matte (the 0.4 mm
// sample, 5 October 2026), so the front goes down. The output is in print orientation.
face_down = "front"; // front or back
qr_mask = -1; // QR mask pattern 0-7; -1 picks the one the standard scores best

// Per nozzle: layer height, the narrowest stroke (about 1.5x the nozzle), the narrowest gap
// between strokes (one line), and the smallest cap height.
fine = nozzle < 0.3;
layer_h = fine ? 0.1 : 0.2;   // slicer layer height (first layer included); thicknesses are multiples of it
min_stroke = fine ? 0.3 : 0.5;
min_gap = fine ? 0.22 : 0.34; // 0.4 nozzle: the slicer's narrowest wall, 85% of the nozzle
min_cap = fine ? 2.5 : 3;

// Card. With a sticker, the layers printed straight after the pause must be a solid black lid over
// it (nfc_lid_t), not the back's inlays: small letters printed onto the sticker's smooth face drag
// into strings (the first print with a sticker, 7 October 2026). So a sticker card has shallower
// back inlays and is 0.2 mm thicker: 1.8 mm with thin stickers, 2.0 mm with thick ones ("thick"
// adds 0.2 mm, so the same 0.2 mm of black still separates the tag from the white QR field). A
// QR-only card stays 1.6 mm with 0.6 mm back inlays.
nfc_enabled = nfc_sticker != "none";
thick_sticker = nfc_sticker == "thick";
card_w = 85.60;    // ID-1 width
card_h = 53.98;    // ID-1 height
corner_r = 3.2;
card_t = !nfc_enabled ? 1.6 : thick_sticker ? 2.0 : 1.8; // total thickness
inlay_t = 0.6;     // depth of the light and accent inlays: opaque enough over black
back_inlay_t = nfc_enabled ? 0.4 : 0.6; // depth of the inlays on the back; 0.4 leaves room for the lid

// QR code: a fixed light field (quiet zone included); the modules scale to fill it, from 1.37 mm
// (version 1) to 1.2 mm (version 2) and 1.07 mm (version 3).
qr_field = 39.6;
qr_quiet = 4;           // quiet zone, in modules
qr_right_margin = 7.19; // card edge to the light field; matches the top and bottom margins
qr_field_r = 1.0;       // corner radius of the light field (inside the quiet zone)
qr_overlap = 0.02;      // grows dark modules so diagonal neighbors overlap instead of meeting at
                        // a zero-width edge, which would make both STLs non-manifold
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

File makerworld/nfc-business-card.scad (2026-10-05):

// MakerWorld version, generated from card.scad by scripts/make_makerworld.py.
// An NFC business card: your name and website on the front, with a QR code and an NFC tag that
// both open your link, and a terminal window with your details on the back.
//
// Open it in OpenSCAD's Customizer (or MakerWorld's) and fill in the first sections; everything
// under [Hidden] is the layout. One colour body per part: body (black), light (white), accent
// (orange) and chrome (grey, the back's window bar). The light and accent parts are flush inlays in
// both faces; the dark QR modules are the black body showing through the white field. The QR code
// is generated here, so the model is a single file.
//
// part = "preview" gives all four in colour; build.sh exports one STL per part with -D part=...

/* [Your details] */
// Your name, over one or two lines. Leave the second line empty for one line.
name_line_1 = "Jane";
name_line_2 = "Doe";
// Shown after "~/" at the top, like a folder in a terminal. Leave empty to leave it out.
handle = "janedoe";
// What the QR code opens. Use the same link when you write the NFC tag. Up to 53 characters.
qr_url = "https://example.com";
// Your website as printed under your name. Leave empty to leave it out.
website_text = "example.com";

/* [Back of the card] */
// Terminal: a terminal window running "whoami". Plain: your name, title and email. None: a plain
// black back, which prints faster with far fewer colour changes.
back_style = "terminal"; // [terminal:Terminal window, plain:Plain, none:None (plain black)]
// Your name as the terminal style prints it. The plain style uses your name from the front.
back_name = "jane doe";
back_title = "product designer";
back_email = "jane@example.com";

/* [Colours] */
// The card itself and the QR code's dark squares.
body_color = "#16181b"; // color
// The QR code's background, your name and the back's text.
light_color = "#f1efe8"; // color
// The "~/", the line under your name, the website and the tap waves.
accent_color = "#ff9f1c"; // color
// The window bar on the back.
chrome_color = "#8e9089"; // color

/* [Printing] */
// The 0.2 mm nozzle prints the sharpest text; the 0.4 mm nozzle is over three times faster.
nozzle = 0.2; // [0.2:0.2 mm nozzle, 0.4:0.4 mm nozzle]
// The NFC tag is optional: without one, the card is QR code only, with no pause in the print.
// With one, measure your stickers: up to 0.20 mm is "thin" (a 1.6 mm card); up to 0.40 mm is
// "thick" (1.8 mm).
nfc_sticker = "thin"; // [none:No NFC tag (QR code only), thin:Thin NFC stickers (0.10-0.20 mm), thick:Thick NFC stickers (0.20-0.40 mm)]

/* [Hidden] */
part = "preview"; // preview, body, light, accent or chrome
// Which face prints against the plate. The plate side comes out flatter and matte (the 0.4 mm
// sample, 5 October 2026), so the front goes down. The output is in print orientation.
face_down = "front"; // front or back
qr_mask = -1; // QR mask pattern 0-7; -1 picks the one the standard scores best

// Per nozzle: layer height, the narrowest stroke (about 1.5x the nozzle), the narrowest gap
// between strokes (one line), and the smallest cap height.
fine = nozzle < 0.3;
layer_h = fine ? 0.1 : 0.2;   // slicer layer height (first layer included); thicknesses are multiples of it
min_stroke = fine ? 0.3 : 0.5;
min_gap = fine ? 0.22 : 0.34; // 0.4 nozzle: the slicer's narrowest wall, 85% of the nozzle
min_cap = fine ? 2.5 : 3;

// Card. "thick" stickers make it 0.2 mm thicker, so the same 0.2 mm of black still separates the
// tag from the white QR field.
nfc_enabled = nfc_sticker != "none";
thick_sticker = nfc_sticker == "thick";
card_w = 85.60;    // ID-1 width
card_h = 53.98;    // ID-1 height
corner_r = 3.2;
card_t = thick_sticker ? 1.8 : 1.6; // total thickness
inlay_t = 0.6;     // depth of the light and accent inlays: opaque enough over black
back_inlay_t = 0.6; // depth of the inlays on the back

// QR code: a fixed light field (quiet zone included); the modules scale to fill it, from 1.37 mm
// (version 1) to 1.2 mm (version 2) and 1.07 mm (version 3).
qr_field = 39.6;
qr_quiet = 4;           // quiet zone, in modules
qr_right_margin = 7.19; // card edge to the light field; matches the top and bottom margins
qr_field_r = 1.0;       // corner radius of the light field (inside the quiet zone)
qr_overlap = 0.02;      // grows dark modules so diagonal neighbours overlap instead of meeting at
                        // a zero-width edge, which would make both STLs non-manifold

// Front text. Sizes are cap heights in mm, and the largest used: longer text shrinks to fit the
// column left of the QR code, down to the smallest size that prints.
text_x = 6.0;                         // left edge of the text column
text_gap = 1.5;                       // text column to the QR field
mark_prefix = "~/";                   // amber, like the site header's "~/tbutman"
mark_name = handle;                   // light
mark_font = "JetBrains Mono:style=ExtraBold";
mark_size = 4.0;
mark_bolden = fine ? 0 : 0.05;        // grows each stroke edge: the mono "a" joint is under 0.5 mm
name_lines = [for (line = [name_line_1, name_line_2]) if (line != "") line];
name_font = "Inter:style=ExtraBold";
name_size = 5.2;
name_leading = 1.45;                  // baseline-to-baseline, as a multiple of the name's size
name_baseline = 30.5;                 // baseline of the first name line, from the bottom edge
accent_w = 10.0;                      // amber rule under the name
accent_h = 0.8;
accent_gap = 3.4;                     // last name baseline to the top of the rule
// "tap" marker in the strip right of the QR code, over the NFC tag: generic NFC waves (not the
// EMVCo payment symbol) and the word "tap", both amber, turned to read upwards. The 0.2 mm sample
// (5 October 2026) printed "tap to connect" cleanly, but the short label reads better at a glance.
// The 0.2 nozzle keeps that sample's lighter Bold at 2.6 mm; the 0.4 nozzle needs ExtraBold at 3 mm.
tap_label = "tap";
tap_font = fine ? "Inter:style=Bold" : "Inter:style=ExtraBold";
tap_size = fine ? 2.6 : 3.0;
// Measured per mm of size: the label's length (to the end of its ink), and the middle of its ink
// (the p's descender to the t's top) above the baseline. Re-measure if the label changes.
tap_label_len = (fine ? 2.14 : 2.18) * tap_size;
tap_label_mid = 0.328 * tap_size;
tap_dot_d = 1.1;                      // the source dot
tap_radii = [1.4, 2.55, 3.7];         // the waves, radiating towards the label; 1.15 mm apart
tap_stroke = 0.6;                     // leaves 0.55 mm of black between waves
tap_spread = 80;                      // degrees covered by each wave; sets the icon's width in the strip
tap_gap = 1.6;                        // icon to label
tap_bolden = fine ? 0 : 0.05;         // grows each stroke edge: the ExtraBold "a" joint is under 0.5 mm
domain_text = website_text;
domain_font = "Inter:style=ExtraBold";
domain_size = 3.2;
domain_bolden = fine ? 0 : 0.03;       // the "a" joint sits right at 0.5 mm

// Back. Terminal style: lines as [amber prompt, light text]; the last line ends in an amber cursor
// block. Plain style: name (light), title (amber) and email (light) in Inter, centred vertically.
back_enabled = back_style != "none";
terminal = back_style == "terminal";
plain = back_style == "plain";
plain_name = str(name_line_1, name_line_1 != "" && name_line_2 != "" ? " " : "", name_line_2);
plain_lines = [for (line = [[plain_name, "light", true], [back_title, "accent", false], [back_email, "light", false]])
    if (line[0] != "") line];             // [text, colour, is the name]
plain_name_size = 4.4;
plain_size = 3.2;
plain_font = "Inter:style=ExtraBold";
plain_bolden = fine ? 0 : 0.03;       // as for the website on the front
plain_name_gap = 7.0;                 // name baseline to the next baseline
plain_gap = 5.4;                      // between the smaller lines
back_lines = [
    ["$ ", "whoami"],
    each [for (line = [back_name, back_title, back_email]) if (line != "") ["", line]],
    ["$ ", ""],
];
back_font = "JetBrains Mono:style=ExtraBold";
back_size = 3.6;
back_bolden = fine ? 0 : 0.05;        // grows each stroke edge: the mono "m" and "a" joints are under 0.5 mm
back_prompt_bolden = fine ? 0 : 0.15; // the mono "$" has a hairline bar
back_leading = 1.75;                  // baseline-to-baseline, as a multiple of back_size
back_x = 6.0;                         // left margin, seen from the back (matches the front)
// Terminal window bar at the top: three dots and a rule, in their own "chrome" part (gray).
back_bar_top = 6.0;                   // card edge to the top of the dots
back_dot_d = 2.2;
back_dot_pitch = 3.6;
back_rule_h = 0.6;
back_rule_gap = 2.4;                  // dots to rule
back_text_gap = 2.8;                  // rule to the top of the first line's capitals
back_cursor = [2.0, 3.6];             // cursor block width and height at back_size
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

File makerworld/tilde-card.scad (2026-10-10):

// Tilde card: a credit-card-sized business card you print all at once on a multi-color printer.
// The front has your name, your website and a QR code that opens your link; an optional NFC
// sticker, sealed inside during the print, lets phones tap it too. Made for Tilde, the free
// Android app that turns your phone into the same card.
//
// Click Customize and fill in the sections: the front, the back, the tap mark, colors and printing.
// The print settings and the pause for the NFC sticker are in the model's description.
//
// Full source, instructions and the developer version: https://github.com/tbutman/tilde-card
// (MIT; CC BY 4.0 on MakerWorld).

/* [Front of the card] */
// Your first name, on the first line. Example: Jane
first_name = "Jane";
// Your last name, on the second line. Leave it empty to fit your whole name on one line. Example: Doe
last_name = "Doe";
// Shown after ~/ at the top, like a folder in a terminal. Leave it empty to leave it out. Example: janedoe
handle = "janedoe";
// The link the QR code opens: up to 53 characters. Write the same one to your NFC sticker. Example: https://example.com
qr_code_link = "https://taptilde.com";
// Your website, printed under your name. Leave it empty to leave it out. Example: example.com
website_on_card = "taptilde.com";

/* [Back of the card] */
// What the back shows. None is plain black and prints fastest, with about half the color changes.
back_style = "terminal"; // [terminal:Terminal window (a command and your lines), plain:Plain (your lines), none:None (plain black)]
// The command shown after $ on the Terminal window back. Example: whoami
terminal_command = "whoami";
// Printed on the back, in either style. Leave a line empty to skip it. Example: jane doe
back_line_1 = "jane doe";
// Printed on the back, in either style. Leave a line empty to skip it. Example: product designer
back_line_2 = "product designer";
// Printed on the back, in either style. Leave a line empty to skip it. Example: jane@example.com
back_line_3 = "jane@example.com";

/* [Tap mark] */
// The word next to the tap waves, up to about 14 characters (17 on the 0.2 mm nozzle). Leave it empty for just the waves. Example: tap to connect
tap_label = "tap";
// Which of your colors the tap waves use, on the front and the back.
tap_waves_color = "accent"; // [accent:Accent color, light:Light color, chrome:Window bar color]
// Which of your colors the tap label uses, on the front and the back.
tap_label_color = "light"; // [light:Light color, accent:Accent color, chrome:Window bar color]
// Show the tap waves on the back too (only with an NFC sticker). "Waves and label" uses your tap label.
back_tap_mark = "no"; // [no:No, waves:Waves only, label:Waves and label]

/* [Colors] */
// The card, and the QR code's dark squares. Keep it dark so the code scans.
card_color = "#16181b"; // color
// The QR code's background, your name, the back's text and the tap label. Keep it light so the code scans.
light_color = "#f1efe8"; // color
// The ~/, the line under your name, your website and the tap waves.
accent_color = "#ff9f1c"; // color
// The window bar on the terminal back.
window_bar_color = "#8e9089"; // color

/* [Printing] */
// Your printer's nozzle. 0.2 mm prints the sharpest text; 0.4 mm is over three times faster.
nozzle = 0.4; // [0.2:0.2 mm nozzle (sharpest), 0.4:0.4 mm nozzle (fastest)]
// An NFC sticker sealed inside lets phones tap the card: round, 22-25 mm (25.5 at most). Thin up to 0.20 mm, thick up to 0.40. Pause at layer 6 (thin) or 7 (thick) on a 0.4 mm nozzle, 11 or 13 on 0.2 mm.
nfc_sticker = "thin"; // [none:No NFC sticker (QR code only), thin:Thin NFC stickers 0.10-0.20 mm (1.8 mm card), thick:Thick NFC stickers 0.20-0.40 mm (2.0 mm card)]

/* [Hidden] */
part = "preview"; // preview, body, light, accent or chrome
// Which face prints against the plate. The plate side comes out flatter and matte, so the front
// goes down. The output is in print orientation.
face_down = "front"; // front or back
qr_mask = -1; // QR mask pattern 0-7; -1 picks the one the standard scores best

// Per nozzle: layer height, the narrowest stroke (about 1.5x the nozzle), the narrowest gap
// between strokes (one line), and the smallest cap height.
fine = nozzle < 0.3;
layer_h = fine ? 0.1 : 0.2;   // slicer layer height (first layer included); thicknesses are multiples of it
min_stroke = fine ? 0.3 : 0.5;
min_gap = fine ? 0.22 : 0.34; // 0.4 nozzle: the slicer's narrowest wall, 85% of the nozzle
min_cap = fine ? 2.5 : 3;

// Card. With a sticker, the layers printed straight after the pause must be a solid black lid over
// it (nfc_lid_t), not the back's inlays: small letters printed onto the sticker's smooth face drag
// into strings (the first print with a sticker, 7 October 2026). So a sticker card has shallower
// back inlays and is 0.2 mm thicker: 1.8 mm with thin stickers, 2.0 mm with thick ones ("thick"
// adds 0.2 mm, so the same 0.2 mm of black still separates the tag from the white QR field). A
// QR-only card stays 1.6 mm with 0.6 mm back inlays.
nfc_enabled = nfc_sticker != "none";
thick_sticker = nfc_sticker == "thick";
card_w = 85.60;    // ID-1 width
card_h = 53.98;    // ID-1 height
corner_r = 3.2;
card_t = !nfc_enabled ? 1.6 : thick_sticker ? 2.0 : 1.8; // total thickness
inlay_t = 0.6;     // depth of the light and accent inlays: opaque enough over black
back_inlay_t = nfc_enabled ? 0.4 : 0.6; // depth of the inlays on the back; 0.4 leaves room for the lid

// QR code: a fixed light field (quiet zone included); the modules scale to fill it, from 1.37 mm
// (version 1) to 1.2 mm (version 2) and 1.07 mm (version 3).
qr_field = 39.6;
qr_quiet = 4;           // quiet zone, in modules
qr_right_margin = 7.19; // card edge to the light field; matches the top and bottom margins
qr_field_r = 1.0;       // corner radius of the light field (inside the quiet zone)
qr_overlap = 0.02;      // grows dark modules so diagonal neighbors overlap instead of meeting at
                        // a zero-width edge, which would make both STLs non-manifold
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

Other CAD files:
out/nozzle-0.2/card-body.stl
out/nozzle-0.4-thick-sticker/card-body.stl
card.local.example.scad
out/makerworld-sample/card-chrome.stl
out/nozzle-0.2-thick-sticker/card-chrome.stl
out/nozzle-0.2/card-chrome.stl
out/nozzle-0.4-thick-sticker/card-chrome.stl
out/nozzle-0.4/card-chrome.stl
test/sticker-test.scad

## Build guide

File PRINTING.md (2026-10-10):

# Printing the Tilde card

This guide is written for a Bambu Lab A1 mini with an AMS lite, using Bambu Studio. Other
multi-color printers work too; the steps are much the same.

The model is free and open source (MIT; CC BY 4.0 on MakerWorld): no account, sign-up or payment,
and the card links straight to your own website. The NFC sticker is optional. Without one you get a
QR card, and you can skip everything about stickers and the pause.

## What you need

- **A printer that prints several colors in a single print**, such as a Bambu Lab printer with an AMS or
  AMS lite. The card changes color about 20 times on a 0.2 mm nozzle, fewer on 0.4 mm (roughly
  half that with no back design), which is too many to do by hand.
- **PLA in black, white and orange**, plus **gray** for the window bar on the terminal-style back
  (optional: use white or orange instead).
- **A 0.2 mm or 0.4 mm nozzle.** See [Choose a nozzle](#choose-a-nozzle).
- **Optional, for a card people can tap:** a round NFC sticker for each card, 22–25 mm across
  (**25.5 mm at most**; see [Buying NFC stickers](#buying-nfc-stickers)), and a phone with NFC plus
  a free app to put your link on the sticker: Tilde (Android) or NFC Tools (iPhone and Android).
- **A textured PEI plate** (recommended). It gives the front a matte finish, which also stops the
  QR code reflecting light.

## Make it yours

The files in `out/` are a sample card for Jane Doe, an example person. To print yours, put in your
details first:

- **On MakerWorld (coming soon; the easiest):** open the model page, click **Customize**, and fill
  in your name, link, website, the back of the card and the colors. Under **Printing**, choose your
  nozzle (it starts on 0.4 mm; see [Choose a nozzle](#choose-a-nozzle)) and whether to add an NFC
  sticker. The preview updates as you type; then open the result in
  Bambu Studio.
- **In OpenSCAD (free, [openscad.org](https://openscad.org)):** open `card.scad`, show the
  Customizer (**Window → Customizer**), change the settings in the first sections and export a
  3MF. Use a recent development snapshot of OpenSCAD: it keeps the four colors in the 3MF.

The choices that change the print:

| Setting | Options |
| --- | --- |
| **NFC sticker** | **No NFC sticker (QR code only):** a QR card, with no pocket, no "tap" marker and no pause. **Thin NFC stickers** or **Thick NFC stickers:** a card people can tap too; see [Buying NFC stickers](#buying-nfc-stickers). |
| **Back of the card** | Three lines of your choice, such as your name, title and email. **Terminal window:** a command such as `$ whoami`, then your lines. **Plain:** just your lines. **None:** plain black, the quickest to print, with roughly half the color changes. Choose None to add your own text or logo in Bambu Studio: the back is the top face as it prints, so the text and color-painting tools work there, and the sticker's pause layer doesn't change. |
| **Nozzle** | **0.2 mm** or **0.4 mm**; see [Choose a nozzle](#choose-a-nozzle). |
| **Tap mark** | With NFC: the word by the tap waves ("tap", or your own, such as "tap to connect"; empty for just the waves); which of your colors the waves and the label use (by default the accent color for the waves and the light color for the label); and whether to repeat the mark on the back, in the strip over the sticker (waves only, or waves and label). The back's text moves a little right to make room. On a None back the mark brings back some color changes, and the window bar color, anywhere on the mark, needs that filament. |

**What fits:** a link of up to 53 characters (shorter is better: the QR code gets bigger squares).
Long names, handles and websites shrink to fit; if something is too long even at the smallest
printable size, the preview stops with a message saying what to change, such as splitting a long
name between **first name** and **last name**. The 0.2 mm nozzle prints smaller text, so more fits.

## Choose a nozzle

The card comes in two versions, one for each nozzle size. They look the same from arm's length;
the difference is in the small text and the print time.

The Customizer starts on the **0.4 mm nozzle**: it's the faster print, the nozzle most printers
come with, and the fully tested preset. Choose 0.2 mm only if your printer has that nozzle fitted:
a 0.2 mm design printed on a 0.4 mm nozzle can lose thin strokes, while a 0.4 mm design on a 0.2 mm
nozzle just comes out a little less sharp. 0.2 mm nozzles also clog more easily: Thomas's clogged
on the last layer of a 4-hour print. If you're new to it, start with 0.4 mm (the default).

| | 0.2 mm nozzle | 0.4 mm nozzle |
| --- | --- | --- |
| **Files** | `out/nozzle-0.2/` | `out/nozzle-0.4/` |
| **Files for thick stickers** | `out/nozzle-0.2-thick-sticker/` | `out/nozzle-0.4-thick-sticker/` |
| **Small text** | Sharp. Every letter prints exactly as designed | The front is clean. Small letters on the back (`m`, `@`, `$`) can come out a little soft or partly filled in |
| **Tap label** ("tap" by default) | Inter Bold, 2.6 mm | Inter ExtraBold, 3 mm (the lighter weight is too fine for this nozzle) |
| **Layers** | 16 layers of 0.1 mm (18 with thin stickers, 20 with thick) | 8 layers of 0.2 mm (9 with thin stickers, 10 with thick) |
| **Color changes** | About 20 per plate (21 in Bambu Studio's estimate for a sticker card with the terminal back) | Fewer |
| **Print time** | About 4 hours for one card (Bambu Studio's estimate for a sticker card with the terminal back, about 21 color changes) | About an hour (not yet measured with the current settings; it was 75 minutes before the paint-layer change) |
| **Filament** | About 10 g in the card, plus the purge at each color change | Similar in the card, less purge |
| **Best for** | The best-looking card, if you have a 0.2 mm nozzle and the time | Most printers come with a 0.4 mm nozzle, and it's several times faster |

**The time is mostly color changes, not the cards.** Color changes happen once per layer for the
whole plate, so printing two or three cards at once takes only a little longer than printing one,
and wastes almost no extra filament. If you're printing a stack of cards, fill the plate. QR-only
cards and plain or no backs are quicker: fewer layers have colors in them.

The 0.2 mm figure is Bambu Studio's estimate for one thin-sticker card with the terminal back on an
A1 mini, sliced from a Customize 3MF with the Tilde card 0.2 mm preset (October 8, 2026). The
0.4 mm figure is an estimate: an early sample took 75 minutes, before the paint-layer change
removed some color layers. Your printer and settings may differ, and the thick-sticker versions
take a little longer (two extra layers on the 0.2 mm nozzle, one on the 0.4 mm).

## Buying NFC stickers

*Only for a card with NFC. Printing a QR card? Skip to [Set up the print](#set-up-the-print-in-bambu-studio).*

You need **round NFC stickers with an NTAG215 chip, 22–25 mm across: 25.5 mm at most**, one per
card. The pocket is about 25.8 mm, so there's only a little room; measure a sticker before you buy
a batch. They're usually sold in packs of 10 to 100, for about **$0.25 to $0.65 per sticker**
($5–10 for a small pack).

**Check the thickness, because it decides which files you print:**

| Sticker thickness | Option (files in `out/`) | The card |
| --- | --- | --- |
| **0.10–0.20 mm** (wet inlays, thin paper stickers) | **Thin stickers** (`out/nozzle-0.2/` or `out/nozzle-0.4/`) | 1.8 mm thick |
| **0.20–0.40 mm** (most thicker paper stickers) | **Thick stickers** (`out/nozzle-0.2-thick-sticker/` or `out/nozzle-0.4-thick-sticker/`) | 2.0 mm thick |
| Over 0.40 mm ("coins", "anti-metal" tags, hard plastic discs) | Not supported | |

If the listing doesn't say, measure one sticker with its backing peeled off, using calipers. If
you can't measure, choose thick stickers: thin stickers work in it too.

**About the chip:** NTAG215 holds 504 bytes, enough for a link or a contact card. NTAG216 (888
bytes) also works. NTAG213 (144 bytes) is enough for a link only.

Some options, with prices as listed on October 5, 2026:

| Where | What | Thickness | Option | Price |
| --- | --- | --- | --- | --- |
| [Seritag](https://seritag.com/nfc-tags/25mm-ntag215-wet) (UK, prices in £/€/$) | 25 mm NTAG215 wet inlay | 0.12 mm | Thin stickers | £0.42 each for 10–99, £0.36 for 100+ |
| [GoToTags](https://store.gototags.com/nfc-sticker-ntag215-25-mm-circle/) (US) | 25 mm NTAG215 paper sticker | 0.35 mm | Thick stickers | $0.54 each in 10s |
| [Tagstand](https://www.tagstand.com/products/ntag215-round-sticker-25mm-diameter/) (US) | 25 mm NTAG215 paper sticker | Not listed: measure | | $0.62 each, $0.44 for 100+ |
| [Amazon](https://www.amazon.com/clp/B091FCQW7N) (K LAKEY, 100 pack) | 25 mm NTAG215 stickers | Not listed: measure | | Varies |
| [eBay](https://www.ebay.com/itm/307182392836) (100 pack) | 25 mm NTAG215 stickers | Not listed: measure | | About $0.37 each |

Listings and prices change; check the diameter (25.5 mm at most), the thickness and "NTAG215" in
the listing before you buy.

## Set up the print in Bambu Studio

New to it? Print a QR card first (**No NFC sticker (QR code only)**): no pause, nothing to buy.

**On a Bambu Lab A1 mini, the presets do steps 1 and 4 for you.** In Bambu Studio, **File →
Import → Import Configs**, choose `bambu/tilde_card_bambu_printer_settings.zip` (or one of its `.json`
files), then pick **Tilde card 0.4 mm** or **Tilde card 0.2 mm** under **Process**. They build on
the A1 mini's standard processes with the four changes below; see [bambu/](bambu/). Both
presets are tested on real prints of a sticker card from a Customize 3MF, paint penetration layers
included: the 0.4 mm one fully, the 0.2 mm one through to the last layer, where a nozzle clog
stopped it. The pause is still
added by hand. **Updating from an earlier version?** Delete the old Tilde card preset first, or
check that Top paint penetration layers shows 2 (0.4 mm) or 4 (0.2 mm) after importing. On other
printers, follow the steps.

1. Install the nozzle you chose. In Bambu Studio, pick your printer with that nozzle (for example
   **Bambu Lab A1 mini 0.2 nozzle**) and its standard process: **0.10mm Standard @BBL A1M 0.2
   nozzle** for the 0.2 mm nozzle, **0.20mm Standard @BBL A1M** for the 0.4 mm nozzle. Other
   printers have their own Standard processes with the same layer heights.
2. Open your card:
   - **Your own card (a 3MF from MakerWorld or OpenSCAD):** open it, then check the four colors
     are assigned to the right filaments (black, white, orange, gray) in the **Filament** list.
     After opening the 3MF, choose the process again (Tilde card 0.4 mm or 0.2 mm, or your
     adjusted standard process): the 3MF brings Bambu's standard process with it. If the name
     shows an asterisk, re-select it and discard the changes. Then check Top paint penetration
     layers shows 2 (0.4 mm) or 4 (0.2 mm).
   - **The sample card (the STLs in `out/`):** drag in all four files from one version's folder at
     once (`card-body.stl`, `card-light.stl`, `card-accent.stl`, `card-chrome.stl`). When asked
     whether to load them as **a single object with multiple parts**, choose **Yes**.
3. If you loaded the STLs, set each part's filament: **body** → black, **light** → white,
   **accent** → orange, **chrome** → gray.
4. Change these four settings:

   | Setting | Where | Change to | Why |
   | --- | --- | --- | --- |
   | Sparse infill density | Strength | **100%** (from 15%), and pattern **Rectilinear**: Bambu Studio offers the switch when you set 100%, choose Yes | Makes the card solid all the way through |
   | Wall generator | Quality | **Arachne** (from Classic) | Fills thin letter strokes properly |
   | Bottom surface pattern | Strength | **Monotonic line** (from Monotonic) | Gives the front an even finish |
   | Top / bottom paint penetration layers | Strength | **2 / 2** on a 0.4 mm nozzle, **4 / 4** on 0.2 mm (from 5 / 3 and 7 / 5) | Keeps the back's colors above the sticker's lid, keeps the black painted up from the pocket's ceiling out of the letters over the pocket, and gives the front 0.4 mm of white with black behind it, which hides the sticker |

   **Why the paint layers matter:** MakerWorld's Customize exports one shape with the colors
   painted on, and Bambu Studio colors each painted face this many layers deep. Its defaults (5 on
   a 0.4 mm nozzle, 7 on 0.2 mm) take the back's letters through the 0.4 mm black lid and onto the
   sticker, where they drag into strings. Bambu also counts the pocket's ceiling (the underside of
   the lid) as a bottom face and paints its black upward, so a bottom value over 2 (0.4 mm) fills
   the back's letters over the pocket with black. 2 / 2 (or 4 / 4) keeps the back's colors above
   the lid, keeps that black out of the letters, and gives the front 0.4 mm of white with black
   behind it, which hides the sticker. The STLs in `out/` are separate parts, so they aren't
   affected; on a QR card (no sticker) the new values are fine too, since 0.4 mm of white is as
   white as 0.6.

   Already right in Bambu's standard profiles; check them if you've changed your defaults or use
   another printer:

   | Setting | Should be | Why |
   | --- | --- | --- |
   | Initial layer height | Same as the layer height (0.10 or 0.20 mm) | The card is built from whole layers |
   | Elephant foot compensation | 0 mm | Keeps small gaps from opening around the front's letters |
   | Top surface pattern | Monotonic line | Gives the back an even finish |
   | Brim | None | |
   | Support | Off (a Customize 3MF turns it on; choosing the process again turns it off) | Support in the pocket would block the sticker |

5. Leave room on the plate for the **prime tower** (the small block the printer purges into when
   it changes color). Drag it onto an empty spot if it's off the plate.
6. Fill the plate: select the card, press **+** to add copies, then **Arrange** (**A**). Three
   cards take barely longer than one, and fit comfortably on the A1 mini's plate.
7. **With an NFC sticker, check the lid before printing:** slice, open **Preview**, set the color
   scheme to **Filament**, and drag the layer slider to the lid layers, right after the pause:
   **6–7** on a 0.4 mm nozzle (**7–8** with thick stickers), **11–14** on 0.2 mm (**13–16** with
   thick stickers). Over the pocket they must be all black. The next layer (**8**, or **9** with
   thick stickers; **15** or **17** on 0.2 mm) must show the back's letter shapes over the pocket
   too, not solid black. And layer **3** (**5** on 0.2 mm) must be black under the front's white.
   If any of these is wrong, the paint penetration layers aren't 2 / 2 (or 4 / 4).

**The card prints face-down, and that's correct.** The side touching the plate comes out
smoothest, so the files are already turned over: you'll see the back facing up, upside down. Don't
flip them.

## Add the pause for the NFC sticker

*Only for a card with NFC. A QR card has no pocket, so it prints straight through.*

The printer needs to stop halfway so you can put the sticker in.

1. Click **Slice plate**, then use the layer slider on the right of the preview.
2. Go to the layer for your nozzle and NFC sticker option. The layer just below it should show an
   open round pocket; this layer should cover it.

   | | 0.2 mm nozzle | 0.4 mm nozzle |
   | --- | --- | --- |
   | Thin stickers (0.10–0.20 mm, 1.8 mm card) | **Layer 11** | **Layer 6** |
   | Thick stickers (0.20–0.40 mm, 2.0 mm card) | **Layer 13** | **Layer 7** |

3. Right-click the **+** on the slider and choose **Add pause**.

When the printer pauses:

1. Peel the backing off a sticker (with your link already on it; see below) and place it **sticky
   side down** on the floor of the pocket, **flat and centered**. Do this for every card on the
   plate. Which side is up doesn't matter for tapping: the card reads from both sides.
2. **Before you resume:** smooth each sticker out, with no bubbles, wrinkles or raised edges, and
   run a fingernail around the rim. A lifted edge or bubble can catch the nozzle, which can drag
   the sticker, leave a bump on the card or knock the print loose, and a sticker that doesn't sit
   fully inside the pocket will be hit by the nozzle.
3. Keep your fingers away from the hot nozzle, then press **Resume** on the printer.

## Put your link on the sticker

*Only for a card with NFC.*

Do this **before** the sticker goes in the card, so a faulty sticker only costs you the sticker.
(You can also rewrite a sticker through the finished card later.)

**On Android, with [Tilde](https://taptilde.com)** (free, the companion app):

1. Fill in your card in Tilde, then go to **Settings** → **Write a sticker**.
2. Choose what the card should open: your website, contact card, LinkedIn and so on.
3. Hold the sticker to the back of your phone until it buzzes. Hold the next one to write that too.

**On iPhone or Android, with NFC Tools** (free, by wakdev):

1. Open NFC Tools and go to **Write** → **Add a record** → **URL / URI**, and type your website
   address.
2. Tap **Write** and hold your phone against the sticker until it confirms.
3. To check: go to **Read** and hold the phone to the sticker. It should show your link.

**Locking is optional and permanent.** Tilde (check **Lock it after writing**) and NFC Tools
(Other → Lock tag) can lock a sticker so nobody can change it, but then you can't either, ever.
Only lock it once the finished card works; you can lock it through the card.

## Check your first card

- The white square behind the QR code is white, not gray or speckled.
- The QR code's squares are crisp, and it scans with your phone's camera.
- With NFC: tapping the card on the "tap" marker opens your link. iPhones read NFC near the top edge, by the
  camera; Android phones usually in the middle or upper part of the back.
- The text is readable, including the small letters.
- The card is flat, with no curled corners (and, with NFC, no bump over the sticker).

## If something goes wrong

- **The white looks gray or has black specks:** increase the flushing volume from black to white
  (the **Flushing volumes** button next to the filament list).
- **Small letters on the front are missing or didn't stick:** wash the plate with dish soap and
  water (fingerprints keep small details from sticking) and lower the initial layer speed, for example
  to 30 mm/s.
- **There's a bump over the sticker:** the sticker is too thick for the pocket. Choose
  thick stickers, or use thinner stickers.
- **The phone doesn't react to a tap:** check NFC is on (Android), move the phone slowly over the
  marker, and check the sticker works by tapping it before printing.

Details on how the model is built are in [docs/DESIGN.md](docs/DESIGN.md).

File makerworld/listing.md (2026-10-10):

# MakerWorld page (draft)

The text below the line is the model page, ready to paste into MakerWorld. Images are in
[images/](images/), in the order they should appear. **Print settings** gives the four changes
twice, as a table and as plain lines: keep whichever MakerWorld's editor shows well, and delete the
other.

**Before publishing:**

- [x] Make the model customizable: upload `tilde-card.scad` (generated by `build.sh`) to
      the Parametric Model Maker. Names, link, handle, website, the back, colors, nozzle and
      sticker thickness are settings; the QR code is generated in the model.
- [ ] After uploading, try it in the Parametric Model Maker: the default Jane Doe card, a long
      name, a 40-character link, both nozzles and both sticker options. Check the 3MF opens in
      Bambu Studio with four colors, and that the fonts are Inter and JetBrains Mono.
- [ ] Print one card from a Parametric Model Maker 3MF and scan it with an iPhone and an Android
      phone.
- [x] Tag thickness: standard pocket for 0.10–0.20 mm stickers, plus a thick-sticker option up to
      0.40 mm (a 2.0 mm card). Make it a setting in the customizer and a profile each.
- [ ] Print and photograph real cards for both nozzles (shot list below).
- [ ] Upload MakerWorld print profiles too, one per nozzle, with the four changes. They're the
      only way the paint penetration layers reach people who open the Customize 3MF straight in
      Bambu Studio without reading the page (Bambu's defaults put the back's colors on the
      sticker). The page also links the A1 mini presets in `bambu/` and lists the changes; the
      pause can't be stored in a customized card.
- [x] Print a sticker card from a Customize 3MF with the paint penetration layers set (check the
      lid in Preview first) and confirm the back prints clean over the sticker. Done October 8,
      2026: 0.4 mm nozzle, the Tilde card 0.4 mm preset (2 / 2), pause at layer 6.
- [x] License: **CC BY 4.0** (anyone may print, remix and sell cards, with credit). The source
      repo is MIT.
- [x] Publish Tilde on GitHub first, and this repo too (or drop its link), so the links below work.

**Trying it in the Parametric Model Maker** (before publishing):

1. Copy the model to the clipboard: `pbcopy < makerworld/tilde-card.scad` (from this repo's
   folder). It's written by `build.sh`; never edit it by hand.
2. Open MakerWorld → MakerLab → **Parametric Model Maker**
   (https://makerworld.com/en/makerlab/parametricModelMaker?pageType=generator), signed in. Start a
   new script and paste it in, or upload the file if the editor offers that. Nothing is public until
   you publish it as a model.
3. Run it: the Jane Doe sample card (taptilde.com, 0.4 mm nozzle) should appear in four colors.
   Then try your own name, a long name, a 40-character link, the 0.2 mm nozzle and thick stickers.
4. Generate the 3MF and open it in Bambu Studio. Check that the fonts are Inter and JetBrains Mono
   (not a fallback), that the four colors can be assigned to filaments, and that nothing times out.

**Photo shot list:** the card in a hand; front and back on a desk; a phone tapping the card with
the website opening; the 0.2 mm and 0.4 mm cards side by side, close up on the small text; the
open pocket at the pause, with a sticker going in; a stack of cards on the plate.

**Images** (model pictures, in this order; MakerWorld has no caption fields, so the captions are
for reference). All are 4:3, the ratio MakerWorld recommends, so its thumbnails show them whole.
`scripts/make_listing_images.py` builds 02–07 from the sample card; the app screenshots it uses are
in `images/app/`.

| File | Caption |
| --- | --- |
| `02-both-sides.png` | Front and back: four colors in a single print |
| `03-front.png` | The front: your name, your link and a QR code |
| `04-back.png` | The back: a terminal window with your details |
| `05-sticker.png` | The NFC sticker goes in at a pause and is sealed inside |
| `06-colors.png` | Your colors (keep the card dark, so the QR code scans) |
| `07-tilde-app.png` | Made for Tilde: your card on your phone |

**Real-life photos:** MakerWorld requires at least three, covering three views (the front, the
back, the card in a hand). See the shot list above.

**Covers:** 4:3 cover: `covers/cover-card-app-title.png` (the same as `01-cover.png`); 3:4 web
cover: `covers/cover-card-app-title-portrait.png`. `scripts/make_covers.py` builds both, plus the
other options in `images/covers/`.

**Fields:** MakerWorld has no summary field, so the Summary below isn't used there; the
description's first lines are what people see first. The model name is 50 characters at most, so
the page uses "Tilde Card: Customizable NFC + QR Business Card" and leaves out "(Free)".

---

## Title

Tilde Card: Customizable NFC + QR Business Card (Free)

## Summary

A free business card you customize and print: a QR code on the front, and an optional NFC
sticker sealed inside so people can tap it too. Prints all at once on a multi-color printer (AMS
or similar). Made for Tilde, the free, open-source Android app that turns your phone into the
same card. Nobody you hand it to needs an app.

## Description

Hand someone this card and they **scan the QR code** to open your website. Add an NFC sticker and
they can **tap it with their phone** too. Their phone doesn't need an app: iPhones and Android
phones with NFC read it right away. It's credit-card size (85.6 × 54 mm), so it fits a wallet, and
it prints all at once on a multi-color printer (AMS or similar).

**Free, with nothing to sign up for.** The model is free (CC BY 4.0) and open source. There's no
account, subscription or service in between: the card opens your own website, and the sticker holds
whatever you write to it.

**Make it yours.** Click **Customize** to type in your name, website, the lines on the back and the
colors (keep the card color dark, so the QR code scans). The QR code is made for your link
automatically, and long text shrinks to fit.

**Choose your card:**
- **NFC sticker:** none (a QR card: no stickers, no pause), or thin or thick NFC stickers, sealed
  inside halfway through the print, invisible and protected. The word by the tap waves is yours
  to change ("tap", "tap to connect", or none), the waves and the word each take one of your
  card's colors, and the tap mark can go on the back too, over the sticker.
- **The back:** a terminal window (`$ whoami`, for the developers; the command is yours to
  change), a plain back, or none, which prints fastest. Both designs print three lines you choose,
  such as your name, title and email.

Want your own design on the back? Choose **None** for a plain back and add your text or logo in
Bambu Studio: the back is the top face as it prints, so the text and color-painting tools work
there, and the sticker's pause layer doesn't change.

**Your whole contact card in one tap.** With an NFC sticker, the card can hold more than a link:
write your **contact card** to it, and one tap offers to save your name, title, company, phone
numbers, email, website and social links to an Android phone's contacts. (iPhones only open links
from a tap, so they open your website instead.) Or write a link, your WhatsApp or your LinkedIn.
Change it any time by writing it again, or lock it so nobody can (that's permanent).

### What you need

- A multi-color printer (AMS, AMS lite or similar). The card changes color about 20 times on a
  0.2 mm nozzle, fewer on 0.4 mm (roughly half that with no back design).
- PLA in black, white and orange, plus gray for the window bar on the terminal back (optional).
- A 0.2 mm or 0.4 mm nozzle.
- **For NFC (optional):** round NTAG215 NFC stickers, 22–25 mm across (**25.5 mm at most**) and up
  to 0.4 mm thick (see below), and a phone with NFC plus a free app to write the sticker: Tilde
  (Android) or NFC Tools (iPhone and Android).

### 0.2 mm or 0.4 mm nozzle?

The Customizer starts on the **0.4 mm nozzle**: it's the faster print, the nozzle most printers
come with, and the fully tested preset. Choose 0.2 mm only if your printer has that nozzle
fitted: a 0.2 mm design printed on a 0.4 mm nozzle can lose thin strokes, while a 0.4 mm design
on a 0.2 mm nozzle just comes out a little less sharp. 0.2 mm nozzles also clog more easily:
Thomas's clogged on the last layer of a 4-hour print. If you're new to it, start with 0.4 mm (the
default). The settings for each are listed below.

- **0.2 mm nozzle:** the sharpest card: every letter prints exactly as designed. About 4 hours
  for one card (Bambu Studio's estimate for a sticker card with the terminal back, about 21 color
  changes).
- **0.4 mm nozzle:** about an hour for one card (not yet measured with the current settings), and
  it's the nozzle most printers come with.
  The front looks clean; the smallest letters on the back can come out slightly soft.

Most of the time goes to color changes, which happen once per layer for the whole plate. So
**two or three cards take barely longer than one**: fill the plate. QR-only cards and plain or no
backs are quicker.

### NFC stickers (optional)

Buy **round NTAG215 stickers, 22–25 mm across: 25.5 mm at most.** The pocket is about 25.8 mm, so
there's only a little room; measure a sticker before you buy a batch. They cost about $0.25–0.65
each ($5–10 for a small pack). Check how thick they are too, because it decides which option you
choose:

- **0.10–0.20 mm** (wet inlays and thin paper stickers): the **Thin NFC stickers** option, a
  1.8 mm card. For example
  [Seritag's 25 mm NTAG215 wet inlay](https://seritag.com/nfc-tags/25mm-ntag215-wet), 0.12 mm.
- **0.20–0.40 mm** (most thicker paper stickers): the **Thick NFC stickers** option, a 2.0 mm
  card. For example [GoToTags' 25 mm NTAG215 sticker](https://store.gototags.com/nfc-sticker-ntag215-25-mm-circle/),
  0.35 mm.
- **Not sure?** Many multipacks don't list a thickness, like these on
  [Amazon](https://www.amazon.com/clp/B091FCQW7N) and [eBay](https://www.ebay.com/itm/307182392836).
  Measure one, or choose **Thick NFC stickers**: thin stickers work in it too.
- **Don't use** NFC coins, anti-metal tags or hard plastic discs. They're too thick.

### How to print

New to it? Print a QR card first (**No NFC sticker (QR code only)**): no pause, nothing to buy.

1. Click **Customize** and fill in your details. Under **Printing**, choose your nozzle (it starts
   on 0.4 mm) and NFC option. Then open it in Bambu Studio.
2. Check the four colors are assigned to the right filaments (black, white, orange, gray) in the
   **Filament** list.
3. Choose the process, even if one is already selected: the 3MF brings Bambu's standard process
   with it. On an A1 mini, choose the Tilde card preset (0.4 mm or 0.2 mm), which already has the
   four changes; on other printers, choose the standard process and make the four changes. See
   **Print settings** below. If the name shows an asterisk, re-select it and discard the changes.
   Then check that Top paint penetration layers shows 2 (0.4 mm) or 4 (0.2 mm).
4. Fill the plate: select the card, press **+** to add copies, then **Arrange** (**A**).
5. **QR card (no NFC): that's it, print it.** With NFC, keep going.
6. Add a pause so you can put the sticker in: slice, then drag the layer slider to the layer in
   this table for your nozzle and the NFC sticker option you chose in Customize (the first layer
   that covers the round pocket), right-click the **+** and choose **Add pause**.

   | | 0.2 mm nozzle | 0.4 mm nozzle |
   | --- | --- | --- |
   | Thin stickers (0.10–0.20 mm, 1.8 mm card) | Layer 11 | Layer 6 |
   | Thick stickers (0.20–0.40 mm, 2.0 mm card) | Layer 13 | Layer 7 |

   Thin stickers: layer 11 (0.2 mm nozzle) or layer 6 (0.4 mm). Thick stickers: layer 13 (0.2 mm)
   or layer 7 (0.4 mm).

7. **Check the lid:** in **Preview**, set the color scheme to **Filament** and drag the slider to
   the layers right after the pause: 6–7 on a 0.4 mm nozzle (7–8 with thick stickers), 11–14 on
   0.2 mm (13–16 with thick). Over the pocket they must be all black. The next layer (8, or 9 with
   thick stickers; 15 or 17 on 0.2 mm) must show the letter shapes over the pocket, and layer 3
   (5 on 0.2 mm) must be black under the front's white. If not, set the paint penetration layers
   to 2 / 2 or 4 / 4 (see **Print settings**).
8. Before printing, write the sticker. With Tilde: Settings → Write a sticker, choose what it opens
   (your website, your contact card, WhatsApp…), then hold the sticker to your phone. With NFC
   Tools: Write → Add a record → URL, then hold it to your phone.
9. When the printer pauses, peel off the backing and place the sticker **sticky side down** on the
   floor of the pocket, **flat and centered**. Which side is up doesn't matter for tapping: the card
   reads from both sides.

   **Before you resume:** smooth it out, with no bubbles, wrinkles or raised edges, and run a
   fingernail around the rim. A lifted edge or bubble can catch the nozzle, which can drag the
   sticker, leave a bump on the card or knock the print loose, and a sticker that doesn't sit
   fully inside the pocket will be hit by the nozzle.
10. Done. Tap it with your phone to try it.

**What fits:** a link of up to 53 characters. Long names shrink to fit; if one is still too long,
the preview tells you what to change (such as splitting it between first name and last name).

The card prints face-down, so you'll see the back on top in the slicer. That's on purpose: the
side on the plate comes out smoothest, so that's the front.

### Print settings

**Bambu Lab A1 mini: use the presets.** Download `tilde_card_bambu_printer_settings.zip` from this
page's **Files & Guides → Other Files** (or from
[github.com/tbutman/tilde-card/tree/main/bambu](https://github.com/tbutman/tilde-card/tree/main/bambu)),
then in Bambu Studio choose **File → Import → Import Configs**, pick the zip, and select
**Tilde card 0.4 mm** or **Tilde card 0.2 mm** under **Process**. They build on the A1 mini's
standard processes with the four changes below. Both presets are tested on real prints of a sticker card
from a Customize 3MF, paint layers included: the 0.4 mm one fully, the 0.2 mm one through to the
last layer, where a nozzle clog stopped it. Add the pause by hand (step 6 above). **Updating from an earlier version?**
Delete the old Tilde card preset first, or check that Top paint penetration layers shows 2
(0.4 mm) or 4 (0.2 mm) after importing.

**Other printers:** pick your printer with the nozzle you chose, and its standard process:
**0.10mm Standard** for a 0.2 mm nozzle, **0.20mm Standard** for a 0.4 mm nozzle. Then change
four settings:

| Setting | Where | Change to | Why |
| --- | --- | --- | --- |
| Sparse infill density | Strength | **100%** (from 15%), and pattern **Rectilinear**: Bambu Studio offers the switch when you set 100%, choose Yes | Makes the card solid all the way through |
| Wall generator | Quality | **Arachne** (from Classic) | Fills thin letter strokes properly |
| Bottom surface pattern | Strength | **Monotonic line** (from Monotonic) | Gives the front an even finish |
| Top / bottom paint penetration layers | Strength | **2 / 2** on a 0.4 mm nozzle, **4 / 4** on 0.2 mm (from 5 / 3 and 7 / 5) | Keeps the back's colors above the lid and the lid's black out of the letters over the pocket, and hides the sticker behind the front |

- **Sparse infill density** (Strength): **100%**, from 15%, and pattern **Rectilinear**: Bambu
  Studio offers the switch when you set 100%, choose Yes. Makes the card solid all the way through.
- **Wall generator** (Quality): **Arachne**, from Classic. Fills thin letter strokes properly.
- **Bottom surface pattern** (Strength): **Monotonic line**, from Monotonic. Gives the front an
  even finish.
- **Top paint penetration layers** (Strength): **2** on a 0.4 mm nozzle, **4** on 0.2 mm, so the
  back's colors stop above the sticker's lid. **Bottom paint penetration layers**: **2** (0.4 mm)
  or **4** (0.2 mm).

**Why the paint layers:** the 3MF from Customize has its colors painted on, and Bambu Studio paints
them this many layers deep. Its defaults (5 on a 0.4 mm nozzle, 7 on 0.2 mm) take the back's
letters through the black lid over the sticker and onto it, where they drag into strings. Bambu
also paints the pocket's ceiling black upward, so more bottom layers fill the letters over the
pocket with black. 2 / 2 (4 / 4 on 0.2 mm) keeps the back's colors above the lid, keeps that black
out of the letters, and gives the front 0.4 mm of white with black behind it, which hides the
sticker. On a QR card (no sticker) the new values are fine too.

Already right in Bambu's standard profiles (check them if you've changed your defaults or use
another printer): initial layer height the same as the layer height, elephant foot compensation 0,
top surface pattern Monotonic line, and support off (a Customize 3MF turns it on, and choosing the
process again turns it off; support in the pocket would block the sticker). A textured PEI plate
gives the front a matte finish with no glare on the QR code.

Full instructions, troubleshooting and the source files:
[github.com/tbutman/tilde-card](https://github.com/tbutman/tilde-card)

### Made for Tilde: your card, on your phone

[Tilde](https://github.com/tbutman/tilde) is a **free, open-source** Android app (MIT) that does
what the card does, from your phone. People tap their phone against yours, or scan the code on
your screen. One tap on your screen switches what you share, to suit who you're talking to:

- **Contact card:** your name, title, company, phone numbers, email, website and social links
  all at once, ready to save to their contacts. (iPhones scan the code on your screen for this one.)
- **A link:** your website, LinkedIn, GitHub, Instagram, X or any link you like.
- **WhatsApp:** opens a chat with you, with a greeting ready to send.
- **Guest Wi-Fi:** joins your network without typing the password.

Keep several cards (work, personal, an event) and switch with a swipe. In English and Portuguese. It
keeps a list of who you've met, and it writes your link or contact card onto this card's NFC
sticker.

No account, no ads, no subscription and no internet permission: your details stay on your phone.
The Tilde card is optional for Tilde users, and Tilde is optional for the card. Download Tilde at
[taptilde.com](https://taptilde.com).

### Get involved

- **Post your make.** A photo of your printed card helps the next person see what it looks like
  in real life.
- **Remix it.** CC BY 4.0: change it however you like, and credit the original.
- **Ideas or problems?** Open an issue on [GitHub](https://github.com/tbutman/tilde-card/issues).
  The model and the Tilde app are both open source, and pull requests are welcome.

## Tags

business card, NFC, QR code, NTAG215, vCard, contact card, multicolor, AMS, customizable, wallet
card, networking, open source

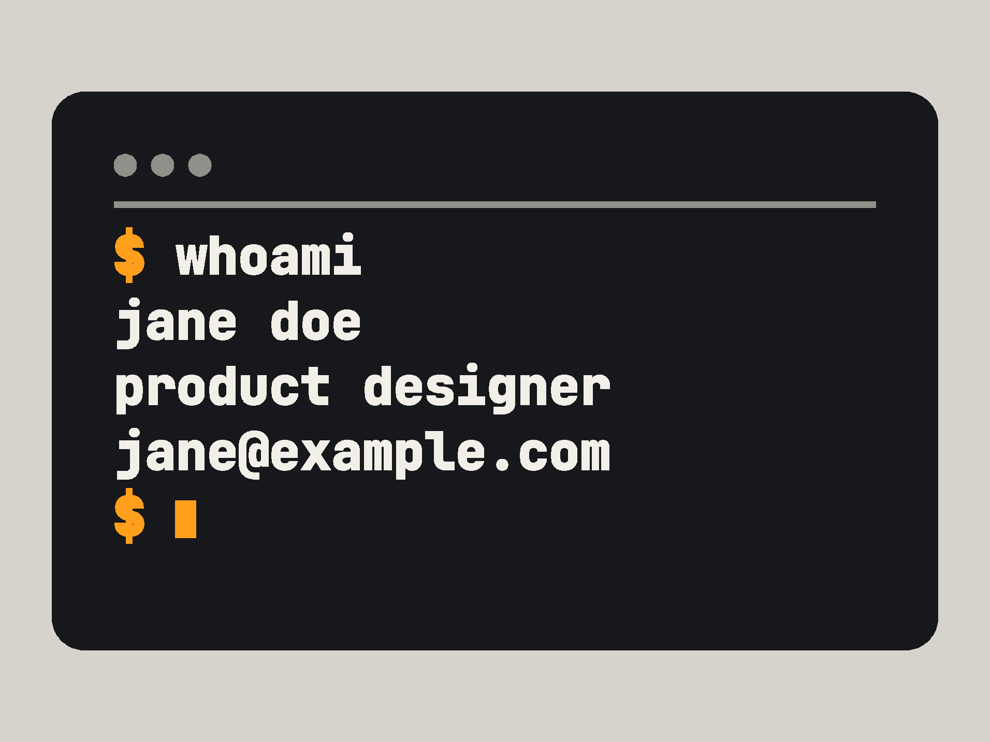
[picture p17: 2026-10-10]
makerworld/images/04-back.png

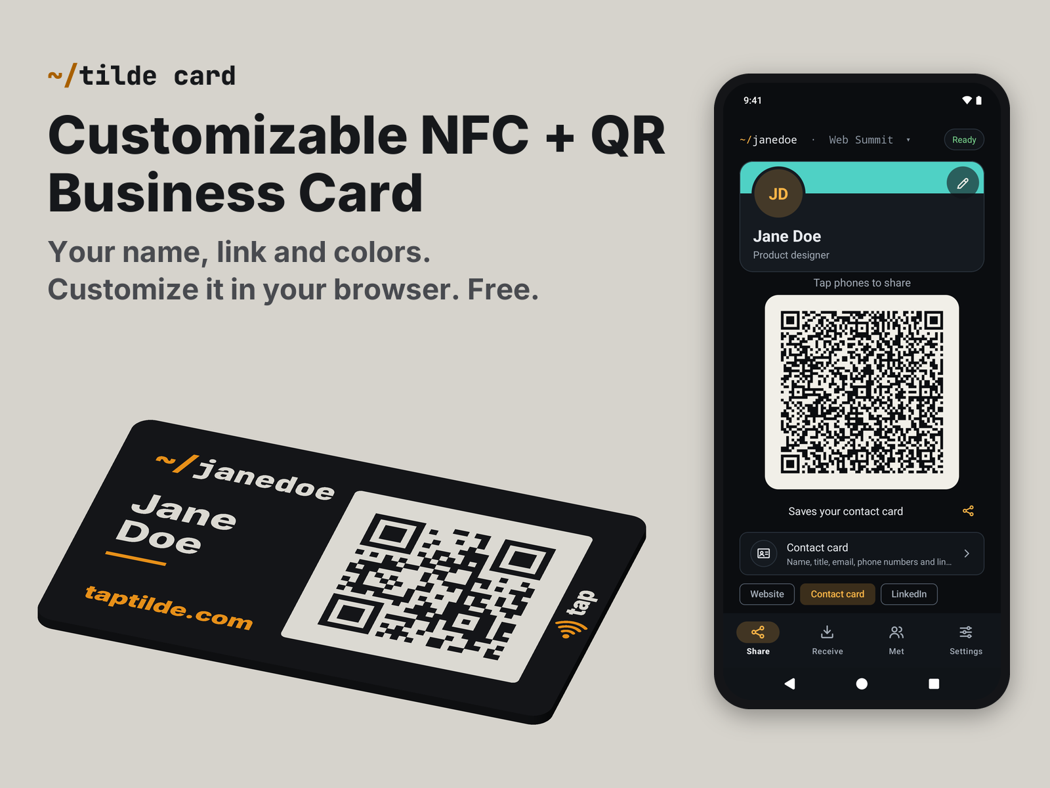
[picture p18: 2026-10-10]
makerworld/images/covers/cover-card-app-title.png

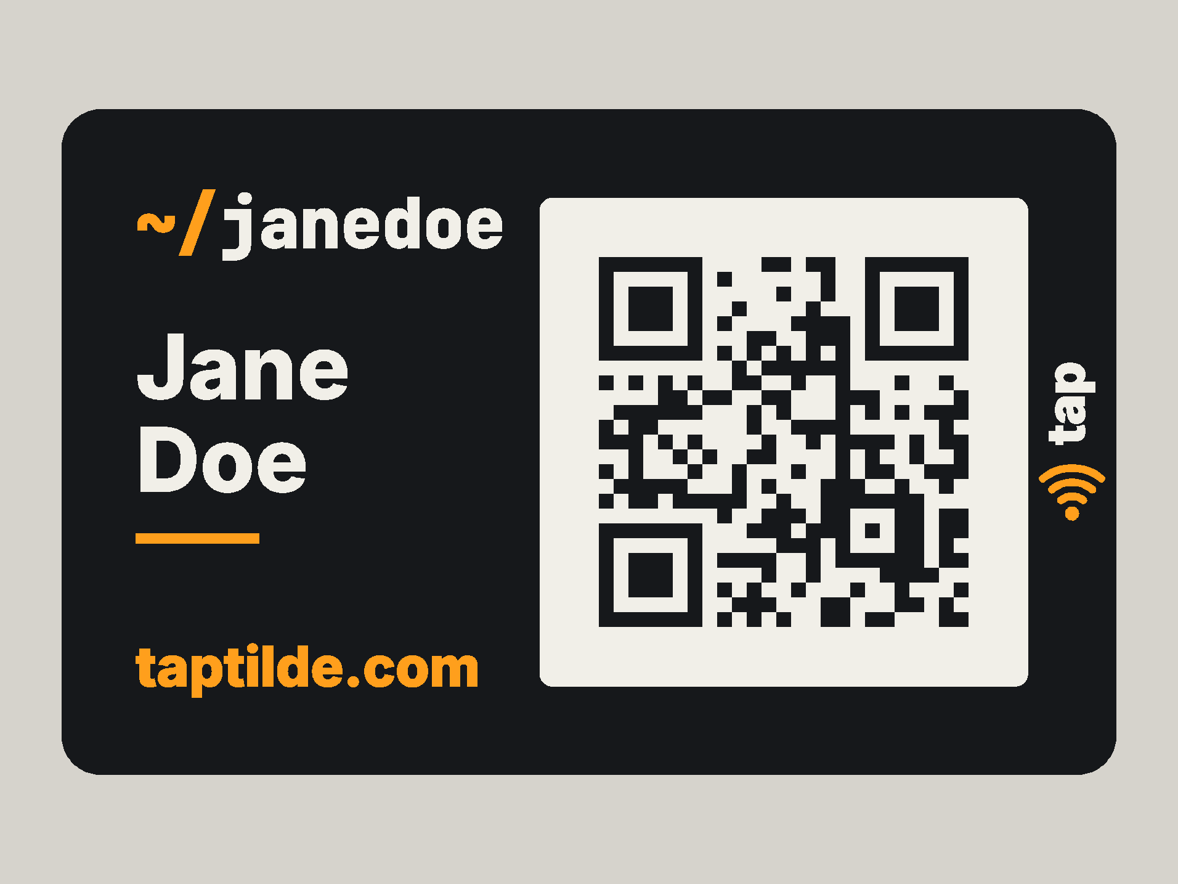
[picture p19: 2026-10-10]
makerworld/images/03-front.png

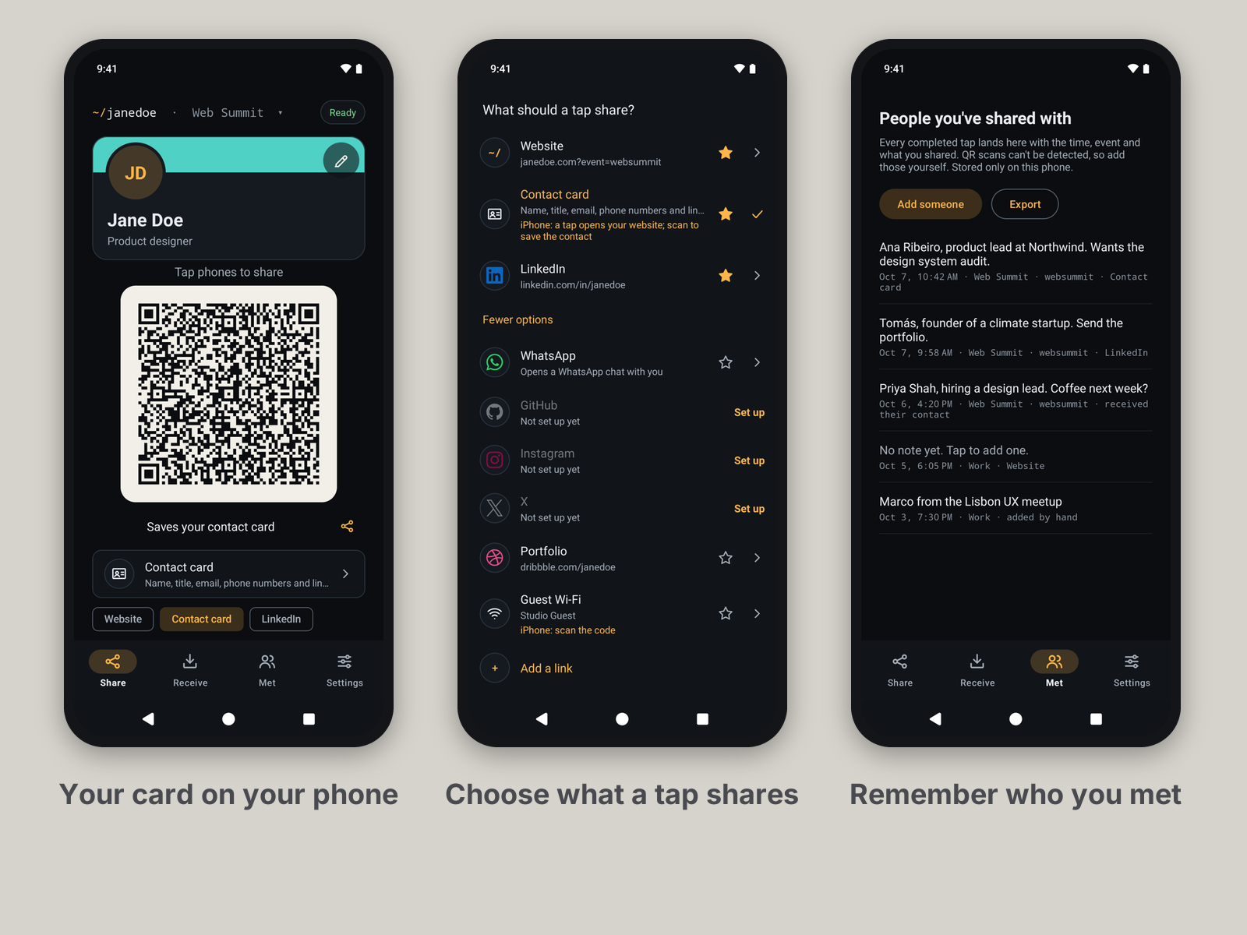
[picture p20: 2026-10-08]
makerworld/images/07-tilde-app.png

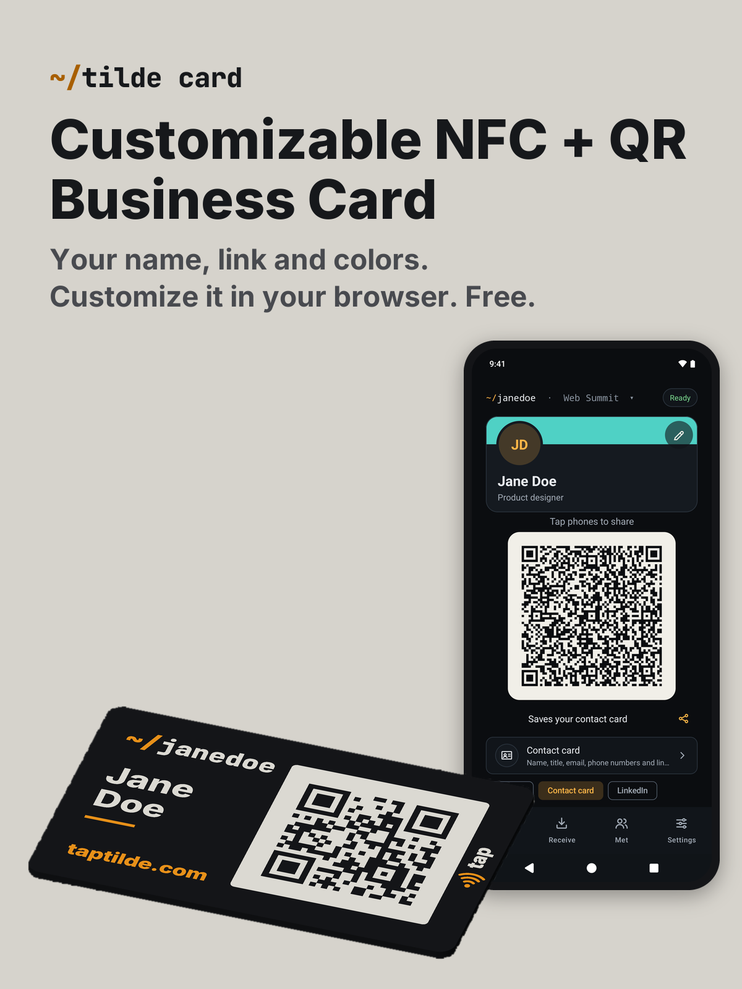
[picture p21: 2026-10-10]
makerworld/images/covers/cover-card-app-title-portrait.png

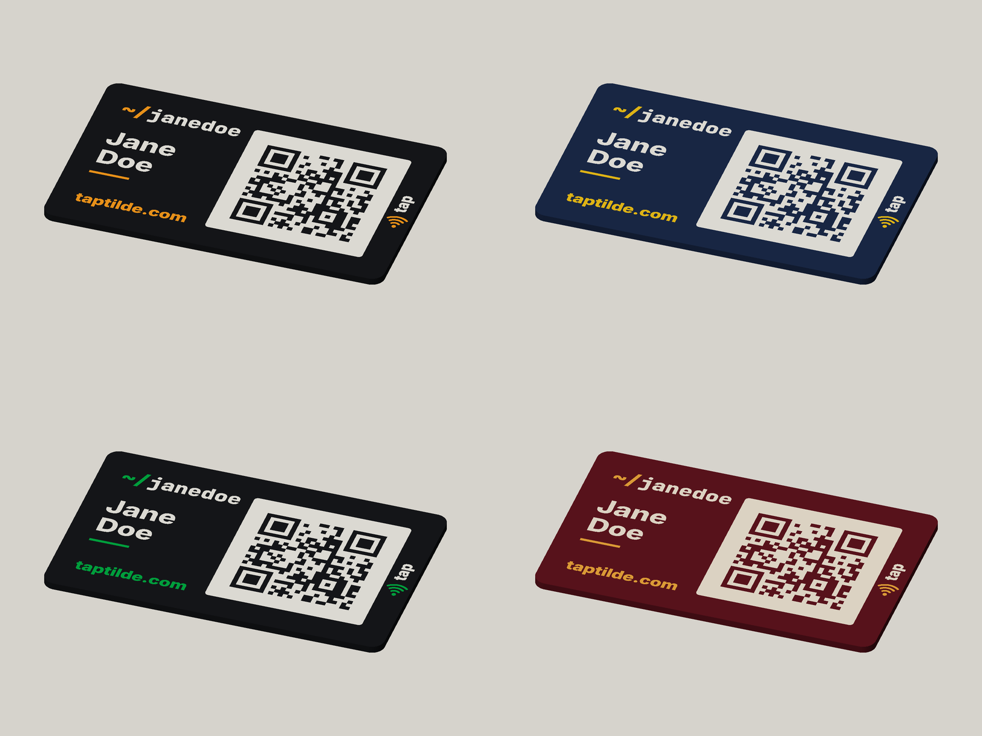
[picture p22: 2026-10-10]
makerworld/images/06-colors.png

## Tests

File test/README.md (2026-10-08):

# Sticker test tile

`sticker-test.scad` is the card-sized tile used on 8 October 2026 to choose how a sticker card's
layers are stacked (see "Solid lid" in [docs/DESIGN.md](../docs/DESIGN.md)). It is 1.8 mm thick,
printed front down, with two thin-sticker pockets: **B** (0.2 mm of black in front of the sticker,
a 0.4 mm lid behind it) and **2** (0.4 mm and 0.2 mm), a white QR-like patch over each on the
front, 0.4 mm white letters over each on the back, and white squares 0.2, 0.4 and 0.6 mm deep.

    test/build-sticker-test.sh [folder]   # inlay-test-body.stl, inlay-test-light.stl, inlay-test.3mf

Load both STLs as one object with multiple parts (body black, light white), with the card's
settings (100% Rectilinear infill, Arachne, bottom Monotonic line). Pause before the layer that
starts at 1.0 mm (sticker in B) and the one that starts at 1.2 mm (sticker in 2):

| Nozzle and process | Pocket B | Pocket 2 |
| --- | --- | --- |
| 0.4 mm, 0.20mm Standard (9 layers) | layer 6 | layer 7 |
| 0.2 mm, 0.10mm Standard (18 layers) | layer 11 | layer 13 |

On the 0.2 mm nozzle, pocket 2's 0.2 mm lid is two layers, so its single-layer lid is only tested
on the 0.4 mm nozzle. Bambu Studio estimates about 2h45m on the 0.2 mm nozzle.

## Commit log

2026-10-04 Parametric 3D-printed business card with QR code and NFC pocket
    OpenSCAD model with one STL per colour, a generated QR matrix, and checks that
    decode the QR code from the exported STLs and measure text stroke widths.
    [card-accent.stl, card-body.stl, card-light.stl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]
2026-10-04 Match the site header: ~/tbutman mark in amber and white
    The mark is set as one string and split by colour so the spacing is the
    font's own. It is 4 mm tall and grown by 0.05 mm so the monospace m and
    a strokes stay at least 0.5 mm. The QR code still decodes from the STLs.
    [card-accent.stl, card-body.stl, card-light.stl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]
2026-10-04 Add a tap marker over the NFC tag and a terminal block on the back
    Front: generic NFC waves and "tap" replace the amber rule, over the tag.
    Back: $ whoami, name, role, email and a cursor, inlaid into the side that
    prints against the plate and mirrored to read correctly. The pocket moves
    up to make room, so the NFC pause is now before layer 5. verify.py checks
    stroke widths on both faces.
    [card-accent.stl, card-body.stl, card-light.stl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]
2026-10-04 Make the back a terminal window: gray title bar, session anchored top left
    Three dots and a rule in a fourth part (card-chrome.stl, gray PLA, or any
    colour assigned in the slicer), with the session anchored under it at the
    front's 6 mm margin. Check images now have transparent corners.
    [card-accent.stl, card-body.stl, card-chrome.stl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]
2026-10-04 Move the tap marker right of the QR code, and the NFC tag under it
    The marker turns to read upwards in the strip right of the QR code, as in
    Thomas's mockup, and the amber rule returns under the name. The NFC pocket
    moves against the right edge, under the QR code, so the marker still sits
    over the tag. The waves keep at least 0.5 mm of black between them, which
    card.scad now checks.
    [card-accent.stl, card-body.stl, card.scad]
2026-10-04 Smaller, centred tap label; add contact and website to the back
    The tap label drops to 3 mm and centres its ink on the icon's axis
    (measured within 0.03 mm). The back adds $ contact and $ website, at the
    3 mm minimum with tighter leading, and card.scad checks the lines still
    fit above the bottom edge.
    [card-accent.stl, card-body.stl, card-chrome.stl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]
2026-10-04 Go back to the five-line back: whoami, name, title, email, cursor
    Eight lines only fit at the 3 mm minimum. The back is pixel-identical to
    46d0f61's; the front keeps the smaller, centred tap label.
    [card-accent.stl, card-body.stl, card-chrome.stl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]
2026-10-05 Print the tap label in white, keeping the waves amber
    verify.py now checks light strokes on both sides of the QR field, so the
    label is covered.
    [card-accent.stl, card-body.stl, card-light.stl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]
2026-10-05 Tune for the 0.2 mm nozzle; tap label reads "tap to connect"
    0.1 mm layers (NFC pause now before layer 9), a 0.3 mm stroke and 0.22 mm
    gap minimum in both card.scad and verify.py, and no glyph thickening. The
    label is Inter Bold at 2.6 mm, because ExtraBold's c and e openings would
    print closed. verify.py now also checks narrow gaps, with the reviewed
    acute corner of the back's w listed.
    [card-accent.stl, card-body.stl, card-light.stl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]
2026-10-05 Build both a 0.2 mm and a 0.4 mm nozzle version from one model
    A nozzle parameter sets layer height, stroke and gap minimums and the few
    design differences (the 0.4 version keeps the "tap" label and thickened
    letters). build.sh exports each to out/nozzle-<size>/ and checks it with
    the same limits. The 0.4 version's narrow gaps are reported as warnings;
    it is pixel-identical to a1a15f1, the design validated for that nozzle.
    [card-accent.stl, card-body.stl, card-chrome.stl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]
2026-10-05 Print the front face-down; log the first sample
    The 0.4 mm sample printed front-down came out with a smooth, matte front
    and a ridged back, so face_down = front is now the default: the STLs are
    exported turned over about the long axis, the NFC pause layers are
    recomputed (before layer 11 at 0.2 mm, layer 6 at 0.4 mm), and verify.py
    and the preview turn each face back before checking it. The rotated faces
    match the old ones to within edge pixels. The 0.4 version's domain grows
    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
    [card-accent.stl, card-body.stl, card-chrome.stl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]
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2026-10-05 Support stickers 0.10-0.20 mm, with a thick-sticker option up to 0.40 mm
    nfc_sticker = "thin" (the default) keeps the 1.6 mm card and its 0.2 mm
    pocket unchanged; "thick" makes the card 1.8 mm with a 0.4 mm pocket, so
    the same 0.2 mm of black stays between the tag and the white QR field
    (now an assertion). build.sh builds both for each nozzle, into
    out/nozzle-<size>-thick-sticker/. Pauses: layer 13 (0.2 mm) and 7
    (0.4 mm) for thick stickers.
    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
    [card-accent.stl, card-body.stl, card-chrome.stl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]
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2026-10-05 Make the card customisable: QR encoder in OpenSCAD, fitted text, MakerWorld file
    - card.scad generates its own QR code (byte mode, versions 1-3, error
    correction M or L), so it is one self-contained file that MakerWorld's
    customizer can run for any link up to 53 characters. The modules scale
    to fill the same 39.6 mm field. scripts/test_qr.py checks all versions
    and masks: ZXing decodes every symbol, and exact-fit symbols match
    segno module for module. gen_qr.py and qr_matrix.scad are gone.
    - Customizer sections: your details, the back, colours (hex, marked for
    MakerWorld's colour pickers) and printing (nozzle, sticker thickness);
    the layout moves under [Hidden].
    - Long names, h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
    [card-accent.stl, card-body.stl, card-chrome.stl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]
2026-10-05 Tap label: "tap" in amber, matching the waves
    The 0.2 mm sample printed "tap to connect" cleanly and came out far
    better than the 0.4 mm one, but the short label reads better at a
    glance. The 0.2 mm version keeps that sample's lighter Inter Bold at
    2.6 mm; the 0.4 mm version stays ExtraBold at 3 mm. Logs the 0.2 mm
    sample and refreshes the MakerWorld images.
    [card-accent.stl, card-body.stl, card-light.stl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]
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2026-10-05 Make the NFC tag optional and add back styles
    - nfc_sticker gains "none": a QR-only card with no pocket, no tap marker
    and no pause. The QR code keeps its place; its margins are already
    even on three sides, with the marker inside the right one.
    - back_style: terminal (as before), plain (name from the front, title in
    amber, email, centred, in Inter) or none (plain black, far fewer colour
    changes). Plain lines shrink to fit like the front's.
    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
    [card-accent.stl, card-body.stl, card-light.stl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]
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2026-10-05 Rename the MakerWorld file to tilde-card.scad
    NFC is optional now, so nfc-business-card.scad no longer described it.
    The model's header says the same.
    [card.scad, tilde-card.scad]
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2026-10-07 MW-06, MW-04, X-01: MakerWorld title and summary; call the print the Tilde card
    The new summary replaces the 'no app needed on either side' line (MW-04)
    with 'Nobody you hand it to needs an app'.
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2026-10-07 X-03: Customizer says NFC sticker, not tag; regenerate the MakerWorld file
    The dropdown reads 'No NFC sticker (QR code only)', and the comments the
    Customizer shows say sticker. build.sh passes, test_qr.py passes, and every
    tracked file in out/ is byte-identical; the MakerWorld file changes only in
    those lines.
    [card.scad, tilde-card.scad]
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2026-10-07 verify.py: reviewed thin-tip exceptions for the stroke check (KNOWN_THIN_TIPS)
    The Jane Doe sample on the 0.4 mm nozzle failed the stroke check at the
    four outer arm tips of the mono 'x' in 'jane@example.com' on the back:
    each loses 0.072 mm^2 to the 0.5 mm opening and prints slightly blunt.
    Like KNOWN_ACUTE_CORNERS for gaps, KNOWN_THIN_TIPS lists reviewed spots
    as (face, x, y) in mm, matched within 0.3 mm, so a change to the text
    brings the check back. Thresholds and CORNER_SLIVER_MM2 are unchanged.
    build.sh now exits 0; no output file changed.
2026-10-07 Back of the card: a terminal command and three lines both styles share
    The back's settings are now back_style, terminal_command ("whoami") and
    back_line_1..3 ("jane doe", "product designer", "jane@example.com"),
    replacing terminal_name, job_title and email. The Terminal window back
    prints "$ <command>", the lines and the cursor, as before; the Plain back
    prints the three lines as typed (first larger, second in amber) instead of
    taking the name from the front. Empty lines are skipped, long ones shrink
    to fit, and clearer asserts say how many characters fit.
    The sample's back text is unchanged, so out/ is byte-identical (the
    plain-back sample passes back_line_1="Jane Doe", as it printed befor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
    [card.local.example.scad, card.scad, tilde-card.scad]
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2026-10-07 MakerWorld file: comments written for makers
    MakerWorld's Model Maker shows the script's comments in its Code panel.
    make_makerworld.py now replaces card.scad's developer header with a short
    one for makers (what the card is; fill in Front of the card, Back of the
    card and Printing; settings and the NFC pause are in the description; the
    source and developer version on GitHub, MIT / CC BY 4.0), and rewrites the
    comments about this repo's tooling and print history (build.sh, verify.py,
    test_qr.py, segno, sample dates). Each replaced comment must match exactly,
    so a change in card.scad stops the script. Every setting keeps its help.
    card.scad: two comments no longer point at the website ('amber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
    [card.scad, tilde-card.scad]
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2026-10-07 Widen the NFC pocket: 0.8 mm clearance, a 25.8 mm pocket
    nfc_clearance 0.3 -> 0.8, so stickers up to 25.5 mm fit. The pocket is
    still 2 mm from the card edge (nfc_center is derived from it) and the
    same depth, so the pause layers are unchanged: thin 11 (0.2 mm) / 6
    (0.4 mm), thick 13 / 7. Only the body STLs change; every surface render
    and preview is byte-identical, so the images stay as they are. The
    nfc_sticker help gives the size: 22-25 mm across, 25.5 mm at most.
    build.sh exits 0; test_qr.py passes.
    [card-body.stl, card.scad, tilde-card.scad]
2026-10-07 Sticker size as a hard maximum, and how to place it at the pause
    The listing (What you need, NFC stickers), PRINTING.md and DESIGN.md say
    round NTAG215 stickers 22-25 mm across, 25.5 mm at most, because the
    pocket is about 25.8 mm; measure one before buying a batch. No more plain
    "25 mm" as if exact (shop product names keep theirs).
    At the pause: sticky side down on the pocket floor, flat and centered;
    "Before you resume": smooth it, no bubbles, wrinkles or raised edges, a
    fingernail around the rim, and why (a lifted edge can catch the nozzle;
    a sticker not fully in the pocket will be hit). Which way up doesn't
    matter for tapping.
2026-10-07 Solid lid over the NFC sticker: shallower back inlays, a thicker card
    Thomas's first print with a sticker: the layers straight after the pause
    were the back's inlays themselves (nfc_floor_t == back_inlay_t == 0.6),
    so whoami, the $ and the name printed as small islands onto the sticker's
    smooth face and dragged into strings. The checks only looked at finished
    surfaces, so they missed it.
    With a sticker only: back inlays 0.6 -> 0.4 mm deep, a 0.4 mm solid black
    lid over the tag (nfc_lid_t; the pocket floor moves to 0.8 mm) and the
    card 0.2 mm thicker: 1.8 mm with thin stickers, 2.0 mm with thick. The
    extra layers are all above the pocket, so the pause layers are unchanged
    (thin 11 / 6, thick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
    [card.scad, tilde-card.scad]
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2026-10-08 Option B chosen: record the sticker test; pause layers in the Customizer help
    - docs/DESIGN.md, "Solid lid (8 October 2026)": what failed (the back's
    letters printed straight onto the sticker), the test tile (pockets B
    and 2), Thomas's results on the 0.4 mm nozzle (no show-through over
    either pocket, clean letters, the two-layer lid flat and the one-layer
    lid rippled, 0.4 and 0.6 mm white the same) and why option B. Two print
    log rows. The tile replaces the earlier inlay strip in test/, with a
    README giving its pause layers for both nozzles.
    - The nfc_sticker help gives the pause layers in one line: 6 (thin) or 7
    (thick) on a 0.4 mm nozzle, 11 or 13 on 0.2 mm.
    - scripts/check_p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
    [card.scad, inlay-test.scad, tilde-card.scad]
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2026-10-08 Checker fixes CARD-CHK-01 to 08: tap label color, presets step, option names
    - CHK-01, 02, 03 (DESIGN.md): the tap label is its own setting, light by
    default; the print log notes the change; colors are named by role.
    - CHK-04 (listing step 3): on an A1 mini the preset already has the three
    changes; other printers make them.
    - CHK-05 (PRINTING.md, listing): NFC sticker options named as the
    Customizer shows them (No NFC sticker (QR code only), Thin NFC stickers,
    Thick NFC stickers).
    - CHK-06 (card.scad help): "Waves and label" in quotes.
    - CHK-07 (card.scad): hidden comments say accent, not amber, and the
    parameter colour is now part_color.
    - CHK-08 (listing checklist): print profile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
    [card.scad, tilde-card.scad]
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2026-10-08 Presets: note to delete an old Tilde card preset, or check the paint layers, when updating
    Bambu Studio may keep an existing preset with the same name, and an older
    export doesn't set the paint penetration layers, so they'd stay at 5 / 3.
    bambu/README.md, PRINTING.md and the listing's preset paragraph say to
    delete the old preset first, or check Top paint penetration layers shows
    2 (0.4 mm) or 4 (0.2 mm) after importing.
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2026-10-10 Print log: the 0.2 mm card from a Customize 3MF; the 0.2 mm preset is tested
    October 8: a Customize 3MF on the Tilde card 0.2 mm preset (paint
    penetration 4 / 4; 3h55m, 21 color changes in Bambu Studio's estimate),
    paused at layer 11. The lid and the letters over the pocket printed
    correctly; the 0.2 mm nozzle clogged on the very last layer, so the
    back's white is one layer short and slightly translucent. A tap test and
    photos are still to come.
    DESIGN.md logs it. bambu/README.md, PRINTING.md and the listing mark the
    0.2 mm preset as tested on a real print (through the last layer, which a
    clog stopped), and the nozzle sections add a caution: 0.2 mm nozzles clog
    more easily, so start with 0.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
2026-10-13 DESIGN.md: option B is print-tested on both nozzles; the 0.4 mm estimate; US dates (card #4, #5)
    - The solid lid section said option B wasn't tested on 0.2 mm or as a full card; both printed
    correctly on October 8 (print log).
    - Print time: Bambu Studio's 53-minute estimate for the 0.4 mm card (card #5; PRINTING.md and the
    listing follow in the next commit).
    - Dates in comments and docs written the US way ("October 8, 2026"). Comments only in card.scad
    and the generated makerworld/tilde-card.scad; build.sh passes and the STLs are unchanged.
2026-10-13 Print time on 0.4 mm: Bambu Studio's estimate, 53 minutes, instead of "not yet measured" (card #5)
    The estimate is for the MakerWorld print profile's card (the Jane Doe sample, thin sticker, terminal
    back, Tilde card 0.4 mm settings). The measured time replaces it once Thomas has one.
2026-10-13 Web Summit sample plate: scripts/make_plate.py writes three cards as one set of STLs (card #14)
    - Three sample cards in a column (85.6 x 171.9 mm), one STL per color, so the four files load in
    Bambu Studio as one object that fills an A1 mini's plate with room for the prime tower.
    - --sticker thin (default, from out/nozzle-0.4/, pause at layer 6, printed by the script) or
    --sticker none: QR-only cards built in Docker and checked with verify.py like build.sh does.
    - Output in out/plates/ (git-ignored); DESIGN.md's file table and PRINTING.md step 6 mention it.
    - Also fixes two DESIGN.md anchors broken by the US-date headings in the previous commit.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
2026-10-13 scripts/check_3mf.py: pass or fail a 3MF against the card's print settings (card improvement A)
    - Wanted values from the presets in bambu/ (paint penetration, infill, Arachne, bottom surface) plus
    the standard-process ones PRINTING.md lists (layer heights, elephant foot 0, top surface, support
    off, brim none or auto).
    - An object's own setting (the Model Maker's dialog writes there) wins over the project's.
    - The pause: the card's thickness gives the sticker, card.scad's help line the layer, and
    custom_gcode_per_layer.xml must pause there (none on a QR card).
    - Tested on synthetic 3MFs shaped like a Customize download, a print profile, a QR card on 0.2 mm
    and a 3MF without settings;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
2026-10-13 Docs pass for phone readers, and "Tilde Card" everywhere (card improvement C, CLAIMS C1)
    - "Tilde Card" in titles and prose (README, PRINTING.md, the listing, DESIGN.md, bambu/), and the
    presets renamed "Tilde Card 0.4 mm" and "Tilde Card 0.2 mm" (names inside the JSON and the zip
    rebuilt; the zip on MakerWorld needs replacing at the next re-sync).
    - PRINTING.md: the wide "choices that change the print" table is now a nested list; the paint
    layers' "why" cell points to the explanation below it instead of repeating it; the presets
    paragraph is shorter, with "Updating from an earlier version?" on its own.
    - listing.md: the plain-line copies of the pause table and the settings table are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
2026-10-13 Card video: the real /tilde page, a Portuguese cut, short loops and a README loop (media #2, I1, I2, #12)
    - The phones open a screenshot of the live tbutman.com/tilde (and /pt/tilde) at a phone's width,
    with its "Scanned a Tilde Card?" strip, under the drawn status bar and address bar, instead of
    the drawn mock (makerworld/video/taptilde-page*.png, from tilde-media/video/page/shoot.mjs).
    - --lang pt: Portuguese captions, notification and end card (16:9 and 1:1, for /pt/tilde).
    - --cut short: an 8-second loop of the tap, the page and the end card (1:1 and 9:16).
    - --cut hero: an 8-second captionless loop (the turn and the colors) and an 800 px GIF for the
    README.
    - The render cache star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
2026-10-13 The card's claims: "Free and open source" instead of "no account" (U4, CLAIMS C4)
    MakerWorld's Customize and download need a MakerWorld account, so the README, PRINTING.md and the
    listing no longer say "no account" or "nothing to sign up for" about the card. They keep what's
    true on every route: free, open source, no subscription or payment, and no service in between.
    The app's own "no account" lines are unchanged.
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
